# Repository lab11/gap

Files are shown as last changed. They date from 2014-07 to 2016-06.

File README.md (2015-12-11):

GAP: Generic Access Point
=========================
<div align="center">
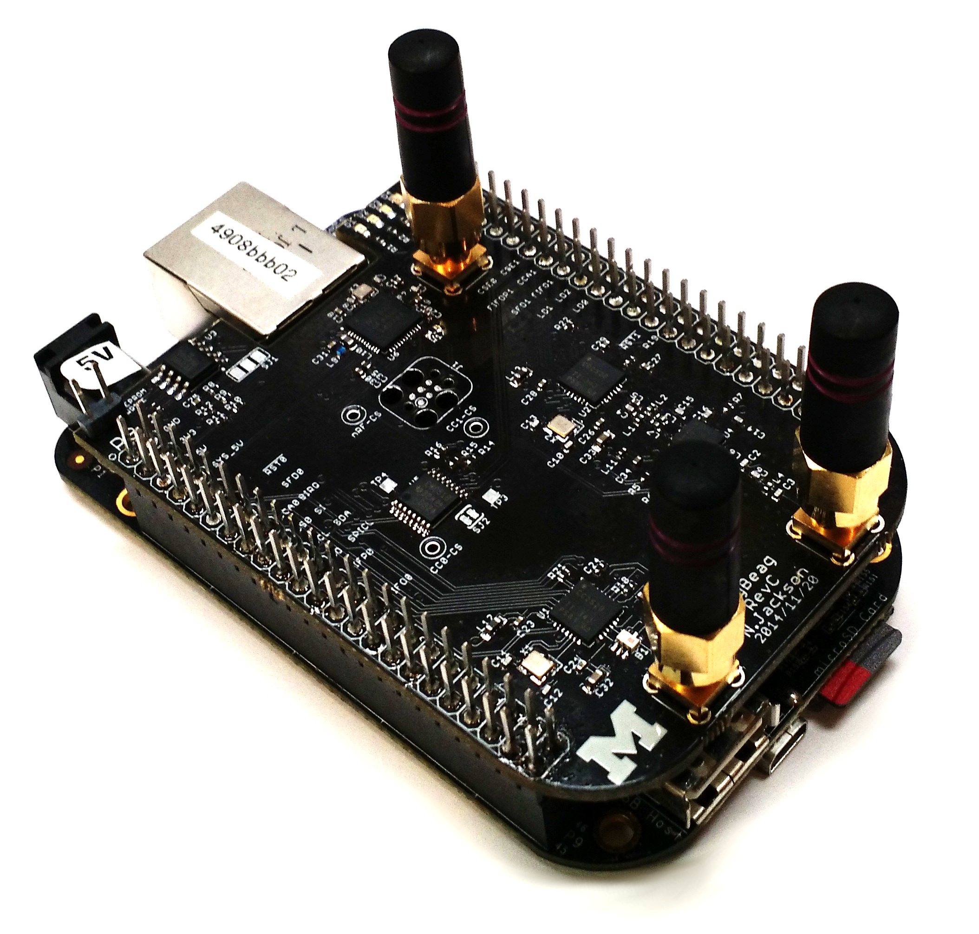
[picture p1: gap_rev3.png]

</div>

GAP is the WiFi router for low-power and embedded Internet of Things devices.
While WiFi routers provide ubiquitous Internet access for laptops and
smartphones, GAP provides Internet access for low-power sensors and wearable
devices. It supports both 802.15.4 and Bluetooth Low Energy.

GAP is implemented as a cape for the
[BeagleBone Black](http://beagleboard.org/black). It uses two TI CC2520 radios
and a Nordic nRF51822 radio to provide connectivity. Each radio has a linux
kernel module to allow userspace access to the radios.

Hardware
--------

The GAP cape features a SPI interface to two CC2520
radios, one of which is amplified with a CC2591, and one nRF51822 radio.
It also includes four LEDs.

Software
--------

The CC2520 radios are
[supported natively](https://github.com/torvalds/linux/blob/master/drivers/net/ieee802154/cc2520.c)
in newer versions of the Linux kernel (>=4.1).

The nRF51822 BLE radio is a work-in-progress. It can be used as a standalone
BLE radio (see [this repo](https://github.com/lab11/nrf5x-base) for a starting
point), but does not have great integration with the BBB at this point.

Setting Up GAP
--------------

To setup a BBB to work with GAP, follow these instructions:

1. Start with a recent build of Debian for the BBB. We suggest starting
with pretty new version of Debian, like that can be found
[here](http://elinux.org/Beagleboard:BeagleBoneBlack_Debian#Jessie_Snapshot_console).

2. Once that is setup, ssh to the BBB and update the kernel to the newest
version. This will not only make sure you're running the latest code,
but also ensure all of the kernel modules will be present.

        sudo apt-get update
        sudo apt-get install vim git lsb-release
        sudo /opt/scripts/tools/update_kernel.sh --beta --bone-channel

    Luckily [Robert C Nelson](https://github.com/RobertCNelson/)
    has made this really easy with a convenient script.

3. Now we have to setup the device tree overlay to let Linux know that
the the radios exist. The GAP overlay and others are setup in a repository also
maintained by RCN.

        git clone https://github.com/lab11/bb.org-overlays
        cd bb.org-overlays
        ./dtc-overlay.sh
        ./install.sh

    That puts the compiled overlay in the correct place, now we need to tell
    the BBB to use it at boot.

        vim /boot/uEnv.txt
        # Edit that line that looks like this to include the reference to GAP
        cape_enable=bone_capemgr.enable_partno=BB-GAP

4. Reboot to apply this.

        sudo reboot

Sniffing 15.4 Packets
---------------------

To make sure everything is working, it is pretty easy to get Linux to
print out the packets the radio is receiving.

1. Install the `wpan-tools` to configure all of the 15.4 devices.

        sudo apt-get install pkg-config libnl-3-dev libnl-genl-3-dev
        wget http://wpan.cakelab.org/releases/wpan-tools-0.5.tar.gz
        tar xf wpan-tools-0.5.tar.gz
        cd wpan-tools-0.5
        ./configure
        make
        sudo make install

1. Install `tcpdump` to view the packets.

        sudo apt-get install tcpdump

2. Configure the network devices. Be sure to set the channel and PANID
to match what is transmitting the 15.4 packets.

        iwpan phy phy0 set channel 0 11
        iwpan dev wpan0 del
        iwpan phy phy0 interface add wpan0 type node c0:98:e5:00:00:00:00:01
        iwpan dev wpan0 set pan_id 0x0022
        /sbin/ifconfig wpan0 up

3. Use `tcpdump` to view them.

        sudo tcpdump -i wpan0 -vvv
        
    OR, use a simple c program to read from the raw socket.
    
        cd linux
        gcc recv_raw_802154.c -o raw
        sudo ./raw
        
    OR, use a very similar python script:
    
        cd linux
        sudo python recv_raw_802154.py

RPL Border Router
----------------

GAP can be setup as a border router running a 6LoWPAN based mesh network
with RPL as a routing layer. It uses [unstrung](https://github.com/mcr/unstrung)
to provide the RPL implementation. The rest is supported by the Linux kernel.

To set this up:

1. Setup the radios and network interfaces:

        sudo iwpan phy phy1 set channel 0 23
        sleep 15
        sudo iwpan dev wpan1 del
        sleep 15
        sudo iwpan phy phy1 interface add wpan1 type node c0:98:e5:00:00:00:00:01
        sleep 15
        sudo iwpan dev wpan1 set pan_id 0x0022
        sleep 15
        sudo ip link add link wpan1 name lowpan1 type lowpan
        sleep 15
        sudo ifconfig lowpan1 up
        sleep 15
        sudo ifconfig wpan1 up

   Note: I've found that putting a sleep between those commands makes everything run smoothly.
   Calling them too quickly seems to break things (at least in the past, it's possible
   that newer commits have solved this issue).

2. Get unstrung.

        git clone https://github.com/mcr/unstrung.git
        cd unstrung
        make

    There may be commits that need to be applied to make this
    work. Look at unstrung pull requests to see if there are
    outstanding patches that are required.

3. Run unstrung.

        /home/debian/unstrung/programs/sunshine/sunshine --verbose --dagid 0x11112222333344445555666677778888 -i lowpan1 -W 10000 --stderr -R 1 --prefix 2607:f018:800:201:c298:e588:4400:1/64 -m

4. You should be able to ping a node:

        sudo ping6 2607:f018:800:201:c298:e522:2200:bb -s 16

<!--

### Setup EEPROM

Now we are getting close. We have told Linux about the kernel modules
and added the device tree overlay to a place where Linux can find it.
The last step is to get Linux to load the overlay which will then cause
it to load the kernel modules. This is where the EEPROM comes in.

When the BeagleBone Black boots it checks for EEPROMs present on any capes
and uses the configuration data in the EEPROM to load the correct device
tree overlay.

There exists a utility to create the hexdump (data.eeprom) to flash to the
EEPROM in `/software/utility`. After creating the hexdump, apply a jumper
to the write header near the EEPROM chip and use this command to flash the
EEPROM:

Choose 12 characters to serve as the serial number, in
the form `WWYY&&&&nnnn`. From the SRM:

    WW = 2 digit week of the year of production.
    YY = 2 digit year of production.
    &&&& = Assembly code, up to you to decide.
    nnnn = incrementing board number for week of production.

After creating `data.eeprom` with the eepromflasher utilty, write it to the
cape EEPROM as root.

    # On the BBB
    sudo su
    cat data.eeprom > /sys/bus/i2c/devices/1-0057/eeprom

Where `1-0057` is the default address for the GAP cape. This can be changed
by using the solder jumper pads near the EEPROM on the upper left corner of the
board.

Unfortunately, the BBB debian distribution fails to load custom firmware from
the EEPROM on boot, and requires an capemanager configuration file to be
edited.

    sudo vim /etc/default/capemgr

    # Add this line:
    CAPE=BB-BONE-GAP

CC2520 Border Router
--------------------

One way to use the CC2520s on GAP is with the TinyOS code in a related
repo: [RaspberryPi-CC2520](https://github.com/lab11/raspberrypi-cc2520).
The `BorderRouter` application can be compiled with `make gap`.
-->

<!--

### EEPROM

The capes feature EEPROM that will allow for the BeagleBone capemgr to auto load the driver
and configure pins on boot, in accordance with the Beaglebone Black SRM. There
exists a utility to create the hexdump (data.eeprom) to flash to the EEPROM in
beaglebone-cc2520/software/utility. After creating the hexdump, apply a jumper
to the write header and use this command to flash the EEPROM:

```bash
cat data.eeprom > /sys/bus/i2c/devices/1-0057/eeprom
```

Where 1-0057 is the default address for the Zigbeag cape. This can be changed by
using the solder jumper pads on the upper left corner of the board.

Software
--------

### Install

This guide assumes the default Angstrom distro running under root.<br/>
Clone the repo to wherever you feel fit:

```bash
git clone https://github.com/lab11/beaglebone-cc2520.git
```

Note: you may have to follow the directions [here](http://derekmolloy.ie/fixing-git-and-curl-certificates-problem-on-beaglebone-blac/) to get git working correctly.

An install script is located in /software. <br/>
The script will copy the Device Tree Overlay (DTO) to /lib/firmware, and the driver to /lib/modules/KERNEL_VERSION, where KERNEL_VERSION is your current running kernel version number. <br/>
Navigate to software/ and run the install script:

```bash
cd beaglebone-cc2520/software/
./install
```

If using the Zigbeag cape with configured EEPROM, just plug it in and reboot the beaglebone and your board will be fully functional.

If EEPROM is not configured, to load the Device Tree Overlay manually:

```bash
echo BB-BONE-CC2520 > /sys/devices/bone_capemgr.9/slots
```
This command should complete with no output.
To check that the DTO has loaded, run:

```bash
cat /sys/devices/bone_capemgr.9/slots
```
Note: bone_capemgr.9 may actually be bone_capemgr.8 for different beaglebones. <br/>
You should check to see that there is now an override board in a slot after the virtual HDMI cape. <br/>
Here is my output:

```
 0: 54:PF---
 1: 55:PF---
 2: 56:PF---
 3: 57:PF---
 4: ff:P-O-L Bone-LT-eMMC-2G,00A0,Texas Instrument,BB-BONE-EMMC-2G
 5: ff:P-O-L Bone-Black-HDMI,00A0,Texas Instrument,BB-BONELT-HDMI
 7: ff:P-O-L Override Board Name,00A0,Override Manuf,BB-BONE-CC2520
```

Now that the DTO is loaded, the pins are now muxed correctly for the cc2520 board. We can now load the driver with:

```bash
modprobe cc2520
```

This command should complete with no output. <br/>
You can check that the driver loaded successfully with:

```bash
lsmod
```

#### Testing
You should now have a functioning Zigbeag cape. There are test programs located in software/driver/tests. Try running the write and read program on two beaglebones, and you should be able to see them talking to each other.

#### Install Issues
If you run into issues with any of the above commands, check dmesg for any output from the kernel. <br/>
Run this to check for issues with loading the DTO:

```bash
dmesg | grep bone_capemgr
```

Run this to check for issues with loading the driver:

```bash
dmesg | grep cc2520
```

### Kernel Module

In order to support the CC2520, you need the kernel module located in software/driver. The install script will automatically copy this into /lib/modules/KERNEL_VERSION. <br/>
This driver has been adapted from the [Linux CC2520 Driver](https:/github.com/ab500/linux-cc2520-driver). <br/>
If you would like to compile the driver from source, there is some setup involved.
I've found it easiest to use a symlink and compile from the current kernel on the Beaglebone.

```bash
opkg update
opkg upgrade
```
It would be a good idea to reboot at this point

```bash
opkg install kernel-headers
opkg install kernel-dev
cd /usr/src/kernel
make scripts
ln -s /usr/src/kernel /lib/modules/$(uname -r)/build
```

You can then navigate to beaglebone-cc2520/software/driver and run make to compile the driver. Make sure you re-run the install script, which will copy cc2520.ko to /lib/modules/KERNEL_VERSION and run depmod -a to register the driver with your system. -->

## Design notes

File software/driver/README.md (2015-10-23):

Custom Kernel Modules for GAP
=============================

These modules are a little out of date, but at one time supported the
radios on GAP.

gapspi.ko
---------

This module uses SPI0 and the onboard demux to switch the SPI bus and 
single chip select to multiple peripherals.

nrf51822.ko
-----------

This provides a SPI connection to the nRF51822.

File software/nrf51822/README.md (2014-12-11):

Setting Up The nRF51822
=======================

This guide explains how to get going with running code on nRF51822 based
platforms.

Setup
=====

1. Get the makefiles. This is an external set of makefiles for the nRF51822.
Apparently they are better than the ones that ship with Nordic's SDK. They
are also on github and can be modified as needed.

        git clone https://github.com/hlnd/nrf51-pure-gcc-setup.git

1. Make sure you have the [arm-none-eabi-gcc](https://launchpad.net/gcc-arm-embedded)
toolchain. You just need the binaries for your platform.

1. Get the nRF51822 SDK and S120 soft device from the
[downloads page](https://www.nordicsemi.com/eng/Products/Bluetooth-Smart-Bluetooth-low-energy/nRF51822?resource=20339).
You want the "nRF51 SDK Zip File" and the "S120 nRF51822 SoftDevice (Production ready)".
You do need to buy a nRF51822 evm kit to get access to these, because companies
are the worst.

1. Get the [Segger flashing tools](http://www.segger.com/jlink-software.html)
for your platform.

Install an Application
======================

1. Make sure the path to the SDK is set correctly in the application
makefile (or override it in your environment).

1. Make sure the path to the gcc Makefiles is set correctly in the application
makefile (or override it in your environment).

1. Just once you need to load the soft device onto the nRF51822. In the application
directory:

        sudo make flash-softdevice SOFTDEVICE=/path/to/softdevice/s120_nrf51822_X.X.X_softdevice.hex

1. Now compile and load the application code.

        sudo make flash

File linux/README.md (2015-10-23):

BBB + GAP + Linux
======================

This provides some instructions for using GAP with Linux.

Setup from new BBB Install
--------------------------

After flashing the BBB, ssh to it and:
```
# lockout root
edit /etc/ssh/sshd_config

# change password
passwd

# packages
sudo apt-get update
sudo apt-get install vim git lsb-release

# update kernel
sudo /opt/scripts/tools/update_kernel.sh --beta --bone-channel

# Add overlays
git clone https://github.com/lab11/bb.org-overlays
cd bb.org-overlays
./dtc-overlay.sh
./install.sh

# Make GAP load on boot
edit /boot/uEnv.txt
  cape_enable=bone_capemgr.enable_partno=BB-GAP

# Reboot
sudo reboot

# Verify
/sbin/ifconfig -a

# Get WPAN tools
sudo apt-get install pkg-config libnl-3-dev libnl-genl-3-dev
wget http://wpan.cakelab.org/releases/wpan-tools-0.5.tar.gz
tar xf wpan-tools-0.5.tar.gz
cd wpan-tools-0.5
./configure
make
sudo make install

```

Sniff broadcast packets
-----------------------

```
sudo apt-get install tcpdump

iwpan phy phy0 set channel 0 11
iwpan dev wpan0 del
iwpan phy phy0 interface add wpan0 type node c0:98:e5:00:00:00:00:01
iwpan dev wpan0 set pan_id 0x0022
/sbin/ifconfig wpan0 up

sudo tcpdump -i wpan0 -vvv
```

Configuring CC2520 with 6LoWPAN
------------------

Once the hardware and software packages are setup, the next step is the art
of using the in-flux tools to get things configured.

1. Set the channel on the physical device.

        iwpan phy phy0 set channel 0 11

1. Create the wpan device. If it exists, delete it first. We need to set the
address.

        iwpan dev wpan0 del
        iwpan phy phy0 interface add wpan0 type node c0:98:e5:00:00:00:00:01

2. Configure the wpan device with a PAN id.

        iwpan dev wpan0 set pan_id 0x0022

3. Add a lowpan device.

        ip link add link wpan0 name lowpan0 type lowpan

4. Bring things up.

        ifconfig lowpan0 up
        ifconfig wpan0 up

5. Ping!

        ping6 fe80::<something>%lowpan0

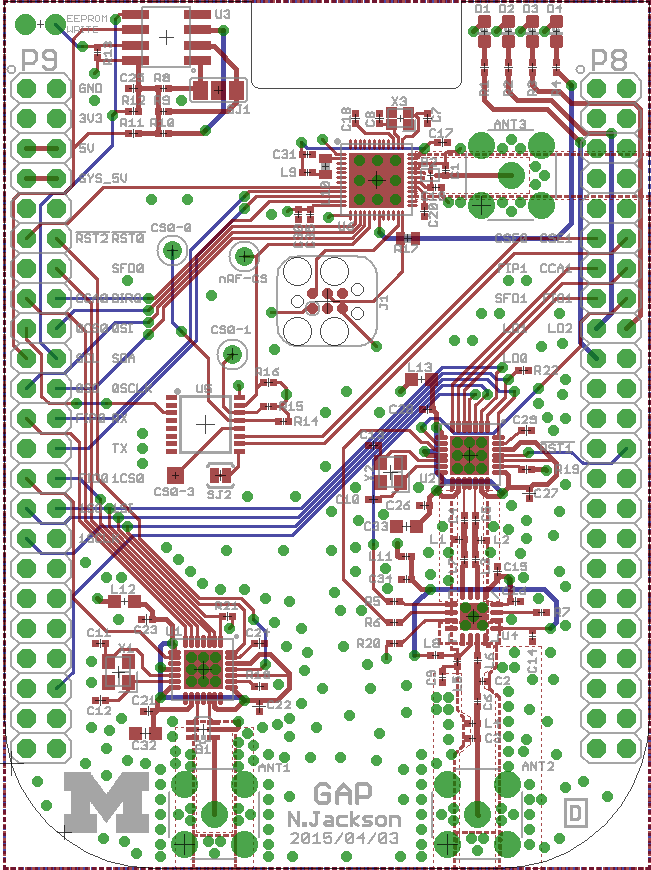
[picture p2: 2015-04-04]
hardware/eagle/bbb-cc2520/rev_d/bbb-cc2520_pcb.png

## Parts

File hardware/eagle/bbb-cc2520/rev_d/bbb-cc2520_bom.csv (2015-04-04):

Qty | Value | Device | Package | Parts | Description | DIGIKEY | SAMTEC | MAJOR LEAGUE
3 | MOLEX_WM5544-ND | MOLEX_WM5544-ND | MOLEX_WM5544-ND | ANT1, ANT2, ANT3 | Through-hole SMA Antenna | WM5544-ND
1 | 2450BM15A0002 | 2450BM15A0002 | 2450BM | B1 | BALUN JTI MATCHED ZIGBEE | 712-1536-1-ND
1 | BAL-NRF01D3 | BAL-NRF01D3 | BAL-NRF01D3 | B2 | 50 ohm nominal input / conjugate match balun to nRF51422-QFAA, | 497-13637-1-ND
1 | 0.8pF | CAPACITOR | 0402_CAP | C1 | 0402 Capacitor | 490-6269-1-ND
1 | 1pF | C-EUC0402 | C0402 | C2 | Capacitor, 1p, 0402, NP0, +/-0.1pF 50V | 490-6206-1-ND
1 | 2.7pF | C-EUC0402 | C0402 | C3 | Capacitor, 2p7, 0402, NP0, +-0.25pF, 50V | 490-5934-1-ND
1 | 3pF | C-EUC0402 | C0402 | C4 | Capacitor, 3p, 0402, NP0, +-0.25pF, 50V | 490-5872-1-ND
1 | 3.9pF | C-EUC0402 | C0402 | C5 | Capacitor, 3p9, 0402, NP0, +-0.25pF, 50V | 490-1272-1-ND
1 | 6.8pF | C-EUC0402 | C0402 | C6 | Capacitor, 6p8, 0402, NP0, +-0.25pF 50V | 490-5949-1-ND
2 | 12pF | CAPACITOR | 0402_CAP | C7, C8 | 0402 Capacitor | 490-6197-1-ND
1 | 15pF | C-EUC0402 | C0402 | C9 | Capacitor, 15p, 0402, NP0, 5%, 50V | 490-5888-1-ND
4 | 27pF | C-EUC0402 | C0402 | C10, C11, C12, C13 | Capacitor, 27p, 0402, NP0, 5%, 50V | 490-5869-1-ND
3 | 1nF | C-EUC0402 | C0402 | C14, C15, C16 | Capacitor, 1n, 0402, NP0, 5%, 50V | 490-3244-1-ND
2 | 1nF | CAPACITOR | 0402_CAP | C17, C18 | 0402 Capacitor | 490-1303-1-ND
1 | 2.2nF | CAPACITOR | 0402_CAP | C19 | 0402 Capacitor | 490-5419-1-ND
1 | 47nF | CAPACITOR | 0402_CAP | C20 | 0402 Capacitor | 445-1264-1-ND
9 | 100nF | C-EUC0402 | C0402 | C21, C22, C23, C24, C25, C26, C27, C28, C29 | Capacitor, 100n, 0402, X5R, 10%, 10V | 490-1318-1-ND
1 | 0.1uF | CAPACITOR | 0402_CAP | C30 | 0402 Capacitor | 445-4952-1-ND
1 | 1uF | CAPACITOR | 0402_CAP | C31 | 0402 Capacitor | 1276-1513-1-ND
2 | 1uF | C-EUC0603 | C0603 | C32, C33 | Capacitor, 1u0, 0603, X5R, 10%, 6.3V | 490-1550-1-ND
1 | 2.2uF | C-EUC0402 | C0402 | C34 | Capacitor, 2u2, 0402, X5R, 20%, 4V | 490-4518-1-ND
1 | 4.7uF | CAPACITOR | 0402_CAP | C35 | 0402 Capacitor | 445-5947-1-ND
1 | GREEN | LED0603 | LED-0603 | D1 | LEDs | 160-1834-1-ND
1 | RED | LED0603 | LED-0603 | D2 | LEDs | 160-1835-1-ND
1 | BLUE | LED0603 | LED-0603 | D3 | LEDs | 160-1837-1-ND
1 | YELLOW | LED0603 | LED-0603 | D4 | LEDs | 160-1831-1-ND
1 | JUMPER-PTH-2-NO | JUMPER-PTH-2-NO | PTH-JUMPER-2-NO_NO_SILK | J2 |  | 3M9447-ND
4 | 1nH | INDUCTOR0402 | C0402 | L1, L2, L3, L4 | Inductor, 1n0, 0402, Monolithic type, +/-0.3 nH | 490-2610-1-ND
1 | 1.1nH | INDUCTOR0402 | C0402 | L5 | Inductor, 1n1, 0402, Monolithic type, +/-0.3 nH | 490-6567-1-ND
1 | 1.5nH | INDUCTOR0402 | C0402 | L6 | Inductor, 1n5, 0402, wire-wound type, +/-0.1 nH | 490-6782-1-ND
1 | 2nH | INDUCTOR0402 | C0402 | L7 | Inductor, 2n0, 0402, +/-0.3 nH | 490-6569-1-ND
1 | 5.1nH | INDUCTOR0402 | C0402 | L8 | Inductor, 5n1, 0402, +/-0.3 nH | 490-6573-1-ND
1 | 15nH | INDUCTOR0402 | 0402_CAP | L9 |  | 587-1521-1-ND
1 | 10uH | INDUCTOR0603 | 0603_CAP | L10 |  | 490-4025-1-ND
1 | 1k Ohm | INDUCTOR0402 | C0402 | L11 | EMI filter bead, 0402 1Kohms GHz Band Gen Use | 490-3999-1-ND
2 | 1k Ohm | INDUCTOR0603 | L0603 | L12, L13 | EMI filter bead, 0603 1Kohms GHz Band Gen Use | 490-1015-1-ND
2 | BBB_HEADERS | BBB_HEADERS | BBB_HEADERS | P8, P9 | 2x23 Pin Header |  | SSQ-123-03-T-D | SSHQ-123-D-08-G-LF
4 | 470 ohm | R-US_R0402 | R0402 | R1, R2, R3, R4 | RESISTOR, American symbol | RHM470CDCT-ND
2 | 1k 1% | R-US_R0402 | R0402 | R5, R6 | RESISTOR, American symbol | RHM1.00KCDCT-ND
1 | 4.3k | R-US_R0402 | R0402 | R7 | RESISTOR, American symbol | 1276-4078-1-ND
3 | 4.75k | R-US_R0402 | R0402 | R8, R9, R10 | RESISTOR, American symbol | 1276-4083-1-ND
2 | 5.6k 5% | R-US_R0402 | R0402 | R11, R12 | RESISTOR, American symbol | RHM5.6KCECT-ND
4 | 10k 1% | R-US_R0402 | R0402 | R13, R14, R15, R16 | RESISTOR, American symbol | RHM10.0KCDCT-ND
1 | 12k | RESISTOR | 0603-RES | R17 | Resistor | RHM12.0KCDCT-ND
2 | 56k 1% | R-US_R0402 | R0402 | R18, R19 | RESISTOR, American symbol | P56.0KLCT-ND
1 | 330k 1% | R-US_R0402 | R0402 | R20 | RESISTOR, American symbol | RHM330KCFCT-ND
2 | 1M 1% | R-US_R0402 | R0402 | R21, R22 | RESISTOR, American symbol | RHM1.00MCDCT-ND
3 | TEST_POINT_0.040IN | TEST_POINT_0.040IN | TESTPOINT_0.040IN | TP0, TP1, TP2 | 0.040in Test Point | 5001K-ND
2 | CC2520 | CC2520 | S-PVQFN-N28 | U1, U2 | 2.4 GHZ IEEE 802.15.4/ZIGBEE® RF TRANSCEIVER | 296-22996-1-ND
1 | CAT24C256WI-GT3 | CAT24C256WI-GT3 | SOIC-8 | U3 | 256kb Serial CMOS EEPROM | CAT24C256WI-GT3OSCT-ND
1 | CC2591 | CC2591 | PVQFN-16 | U4 | 2.4GHz Range Extender | 296-23603-1-ND
1 | CD4051B-53B | CD4051B-53B | TSSOP16 | U5 | IC MUX/DEMUX 8x1 16TSSOP | 296-11993-1-ND
1 | NRF51822QF | NRF51822QF | QFN-48-6MM | U6 | Multiprotocol Bluetooth® 4.0 low energy/2.4 GHz RF SoC 32kB/256kB | 1490-1042-1-ND
2 | NX2520SA | NX2520SA | NX2520SA | X1, X2 | CRYSTAL 32MHZ 10PF SMD | 644-1065-1-ND
1 | 16MHz | TXC-8Y | TXC-8Y | X3 | 2mmx1.6mm SMD Crystal | 887-2003-1-ND

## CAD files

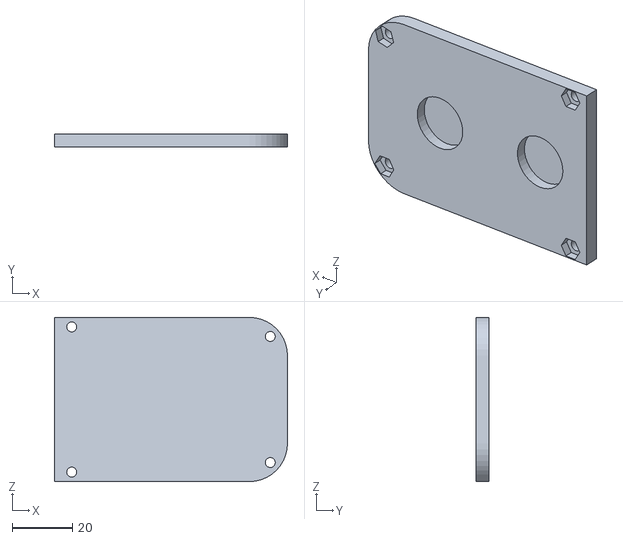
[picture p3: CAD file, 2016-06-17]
3d/beagle_bone_gateway_magnet_plate_v3.STL
77.5 x 4.48 x 54.6

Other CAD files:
3d/beagle_bone_gateway_magnet_plate.SLDPRT
3d/beagle_bone_gateway_magnet_plate_v2.STL
3d/beagle_bone_gateway_magnet_plate.STL

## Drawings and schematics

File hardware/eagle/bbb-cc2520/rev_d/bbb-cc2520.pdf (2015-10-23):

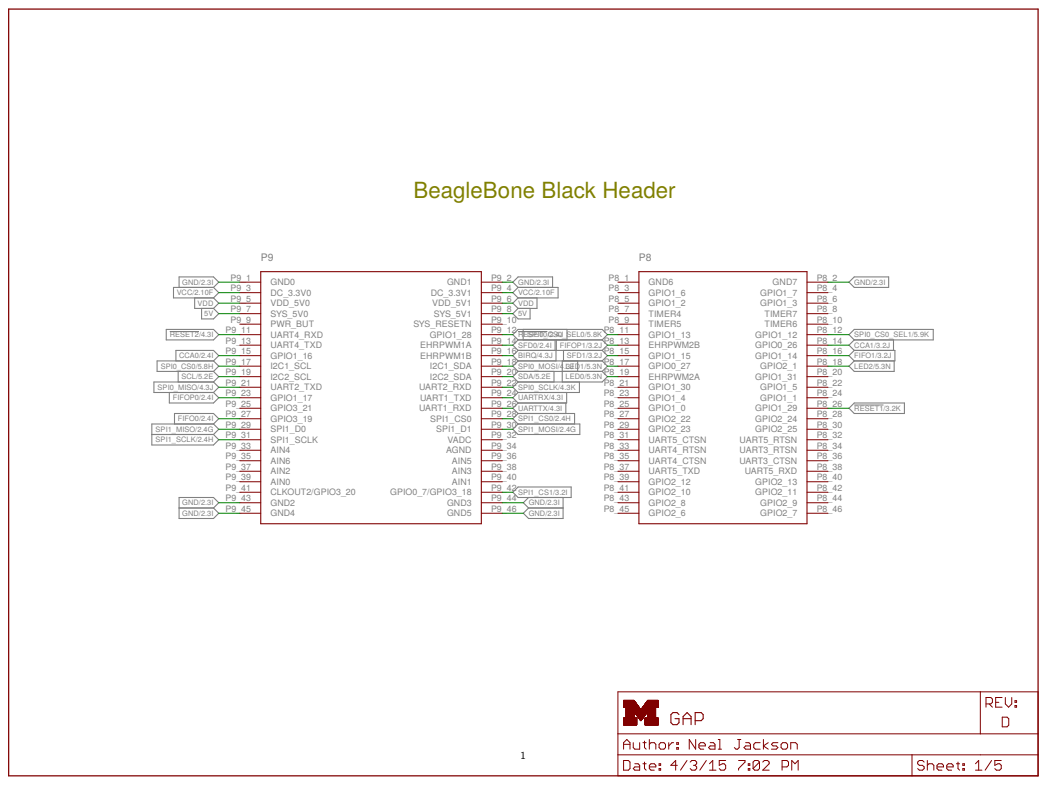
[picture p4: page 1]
1 BeagleBone Black Header GND0 P9_1; GND1; P9_4 VDD_5V0 P9_5; VDD_5V1; P9_6 SYS_5V0 P9_7; SYS_5V1; P9_8 PWR_BUT P9_9; SYS_RESETN; P9_10 UART4_RXD P9_11; GPIO1_28; P9_12 UART4_TXD P9_13; EHRPWM1A; P9_14 GPIO1_16 P9_15; EHRPWM1B; P9_16 I2C1_SCL P9_17; I2C1_SDA; P9_18 I2C2_SCL P9_19; I2C2_SDA; P9_20 UART2_TXD P9_21; UART2_RXD; P9_22 GPIO1_17 P9_23; UART1_TXD; P9_24 GPIO3_21 P9_25; UART1_RXD; P9_26 GPIO3_19 P9_27; SPI1_CS0; P9_28 SPI1_D0 P9_29; SPI1_D1; P9_30 SPI1_SCLK P9_31; VADC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

# CC2520. Index: 0, no amplifier

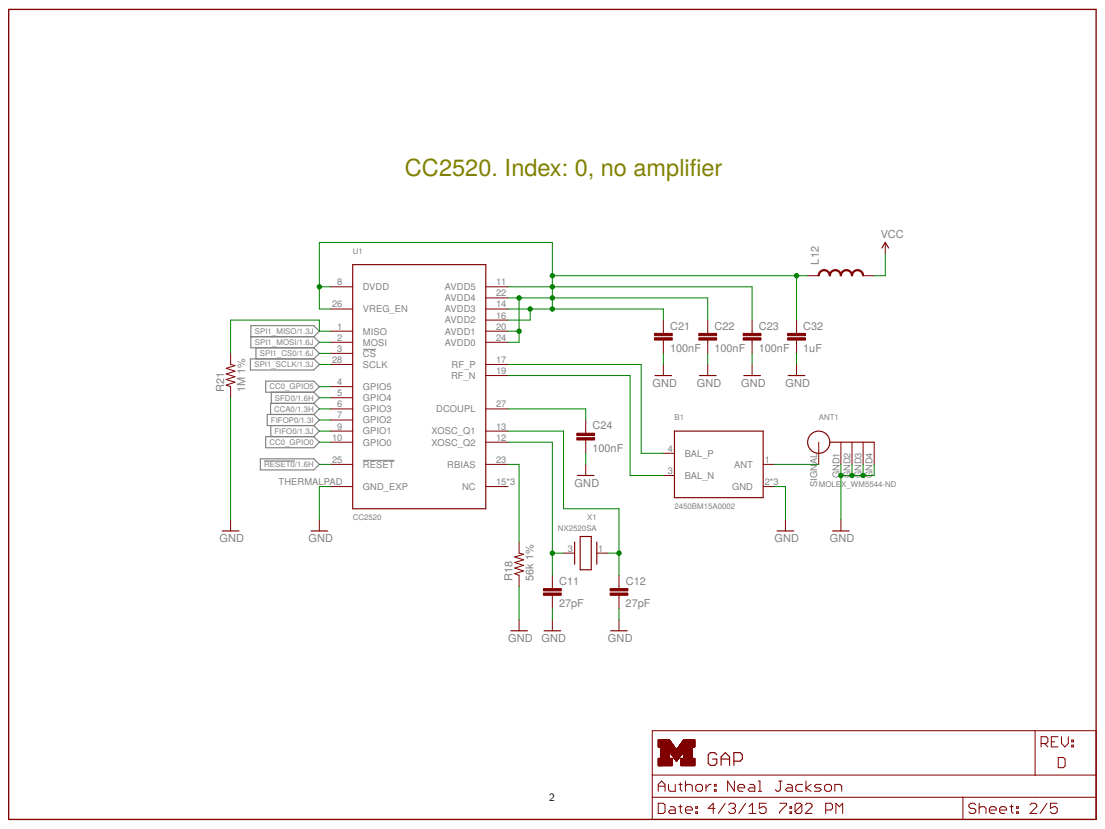
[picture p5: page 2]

14
16

# CC2520. Index: 1, with amplifier

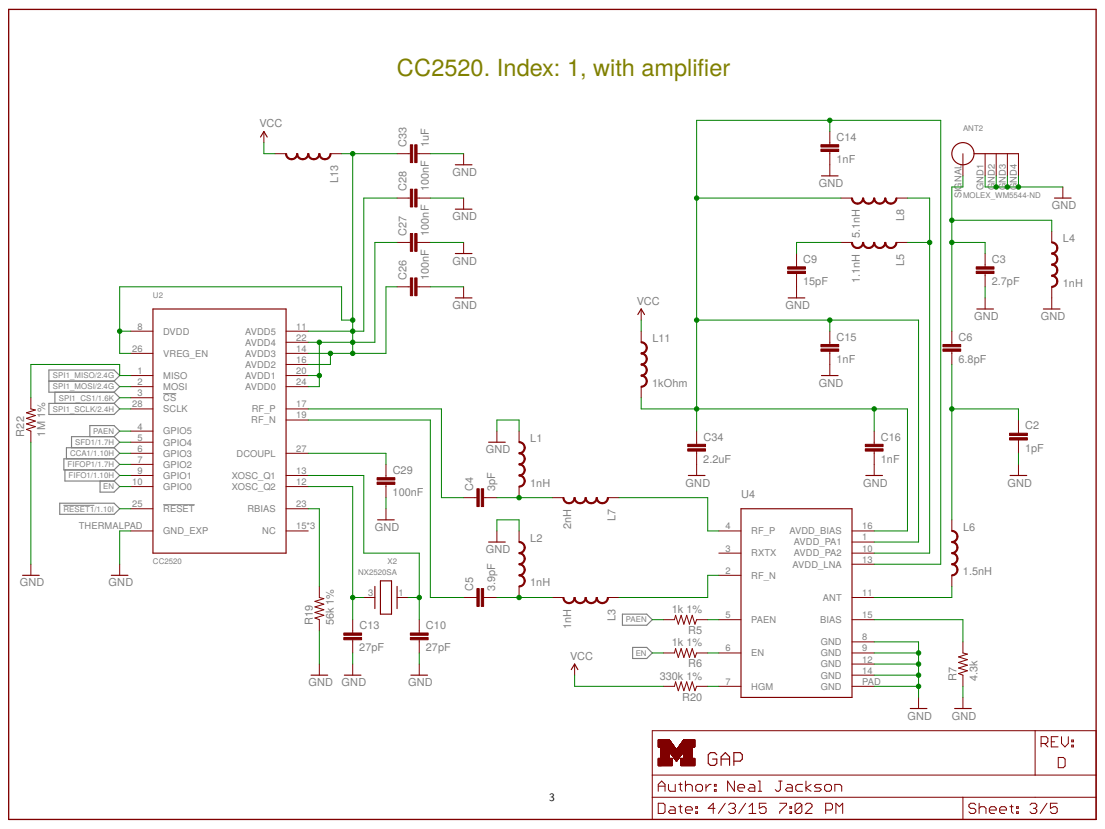
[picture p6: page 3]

14
16

# nRF51822

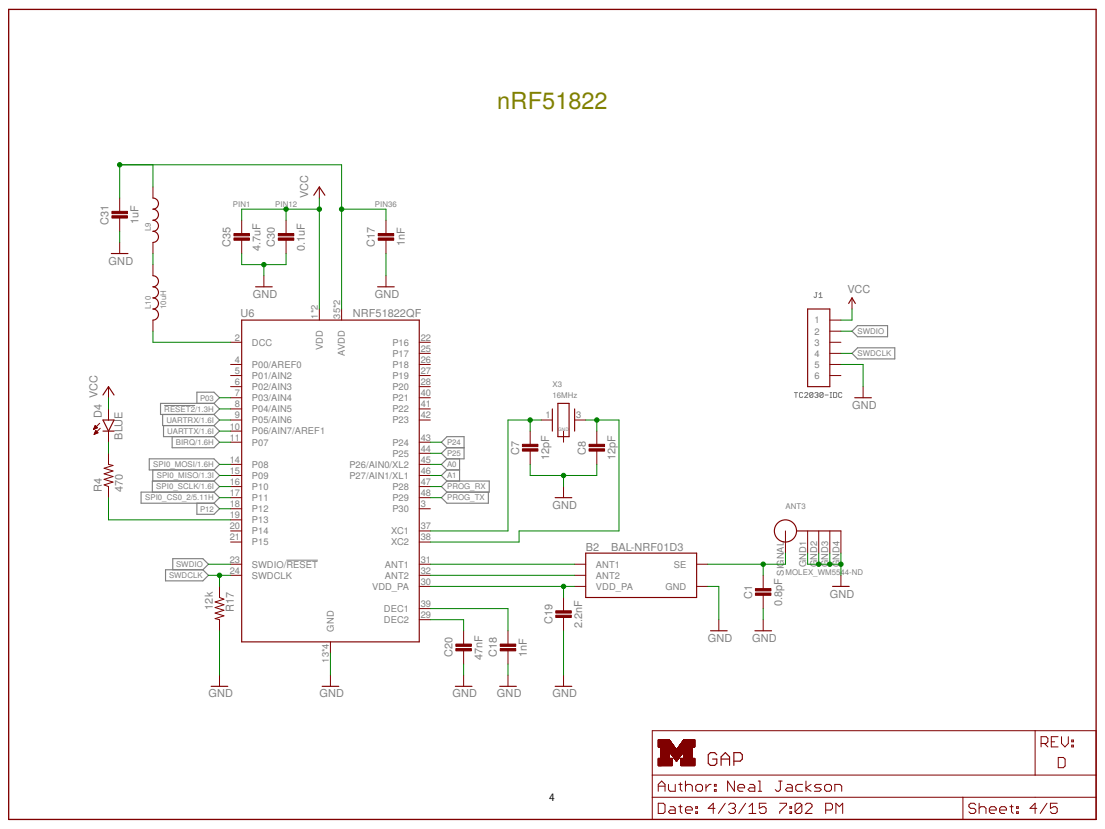
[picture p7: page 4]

# Chip Select DeMux

# EEPROM

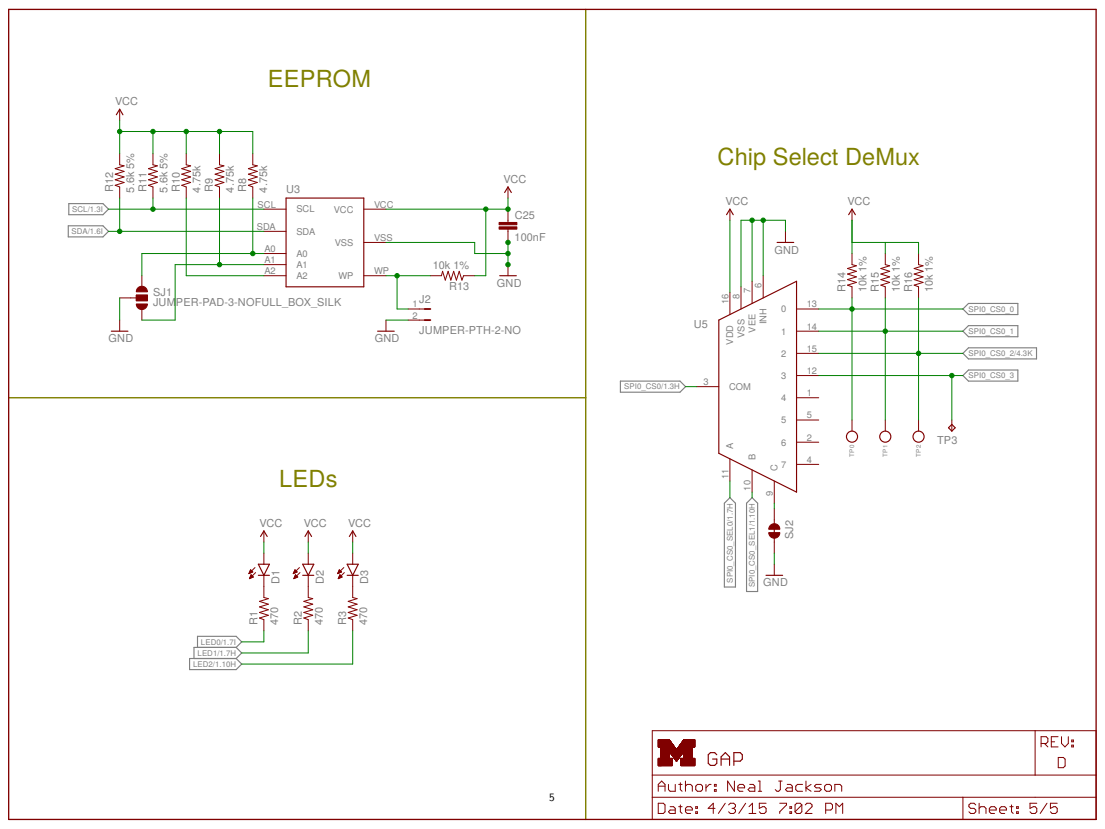
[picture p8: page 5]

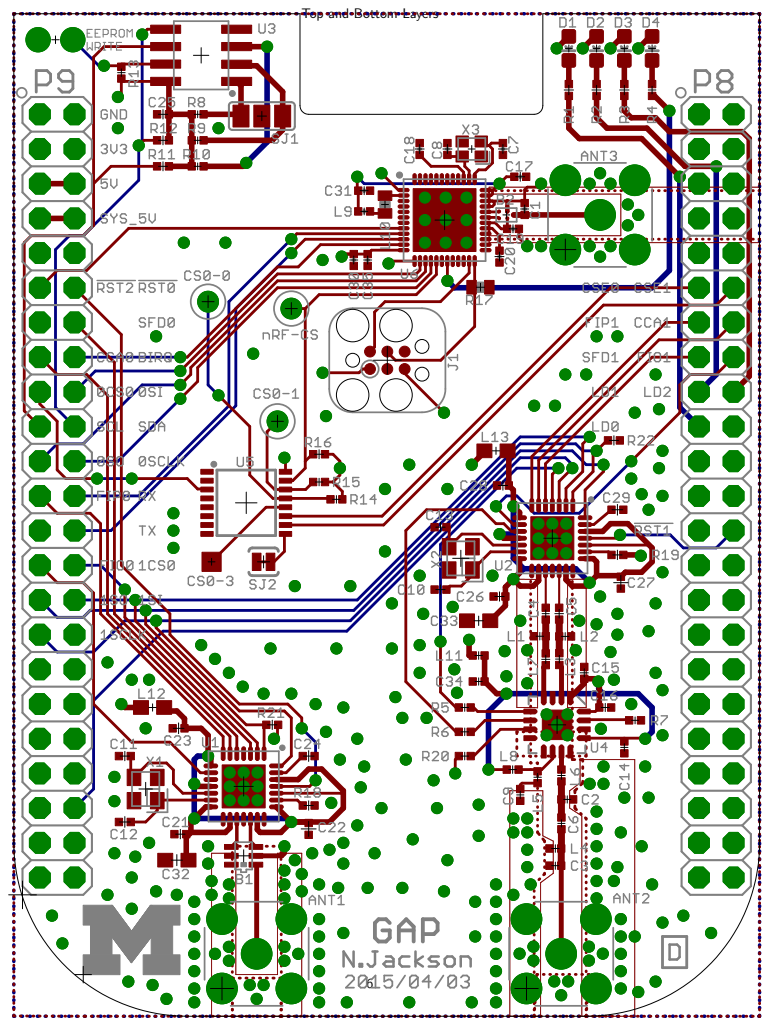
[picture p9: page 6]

Top and Bottom Layers

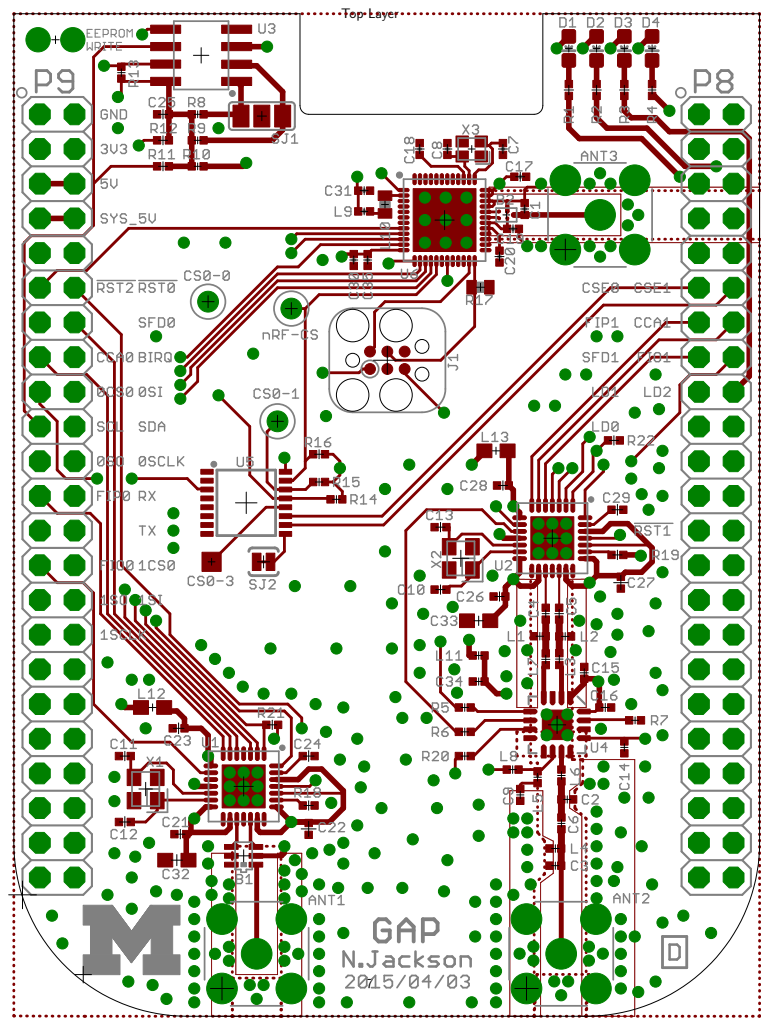
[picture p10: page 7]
Top Layer

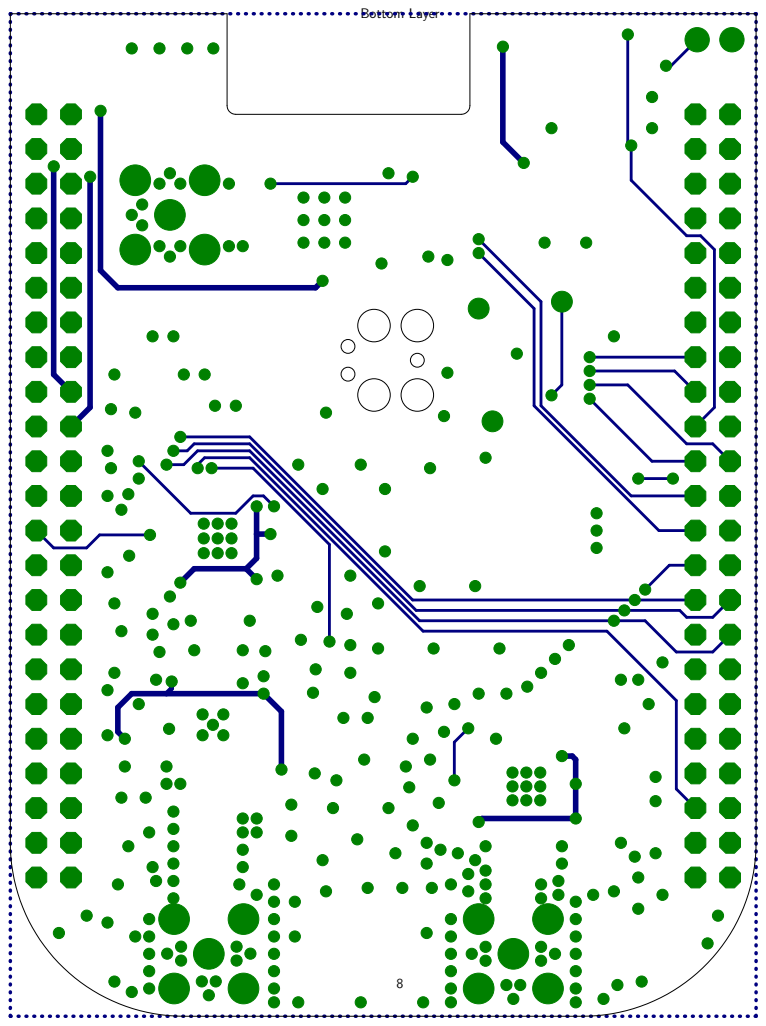
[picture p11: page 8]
Bottom Layer

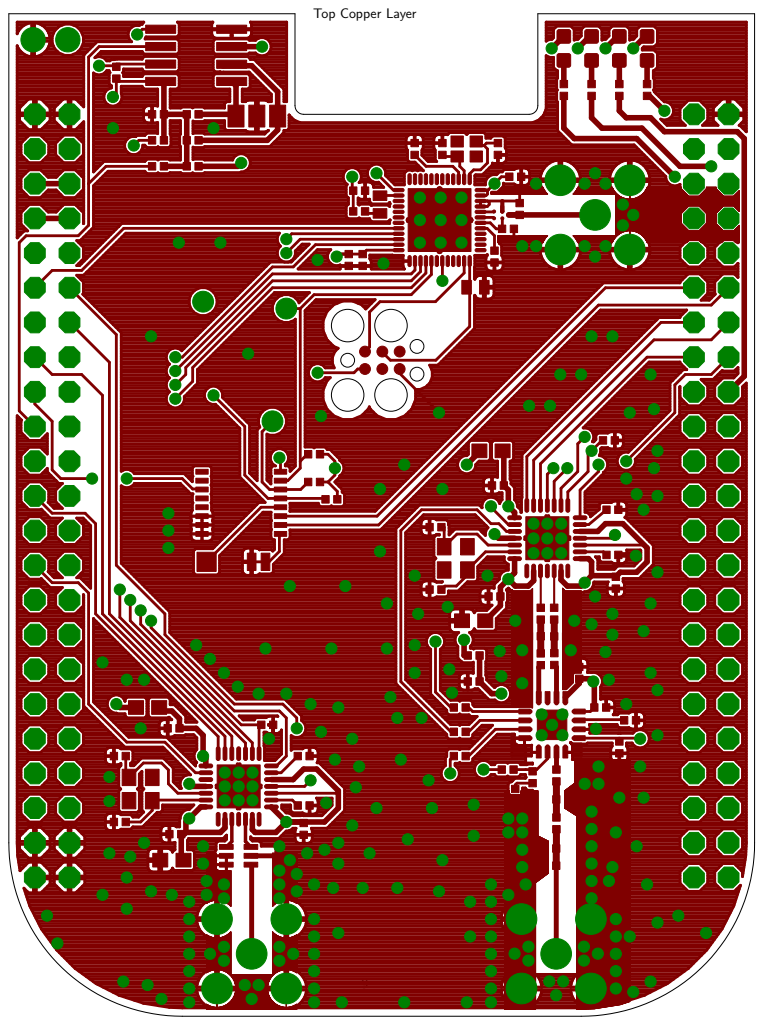
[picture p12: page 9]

Top Copper Layer

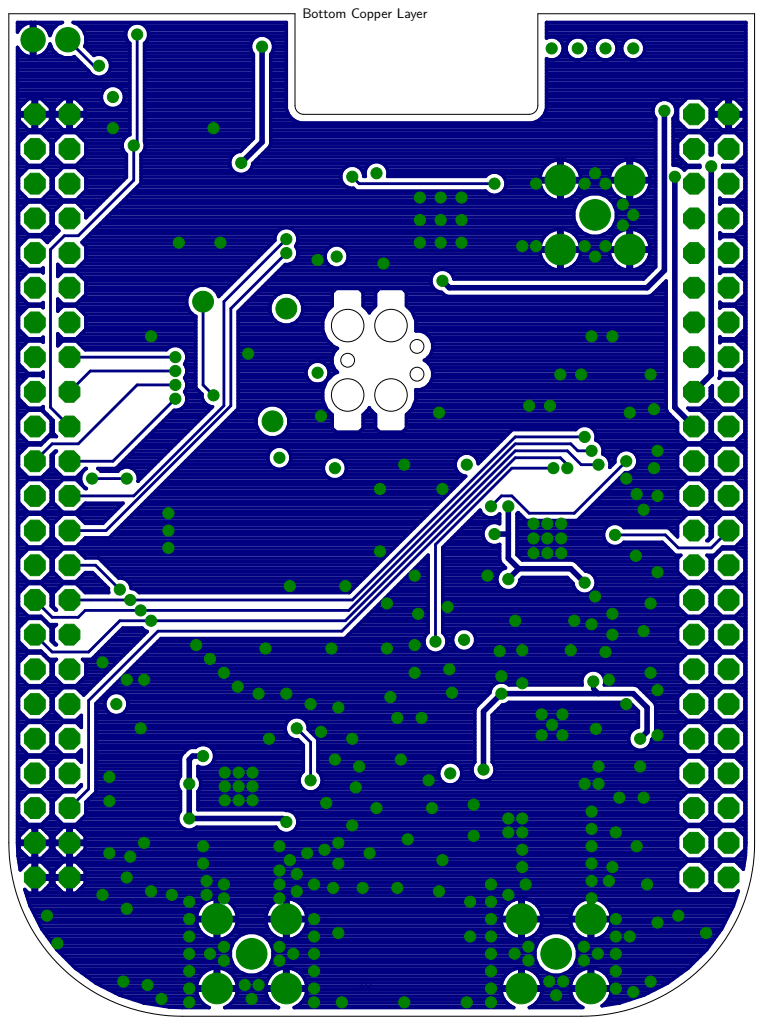
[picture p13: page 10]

Bottom Copper Layer

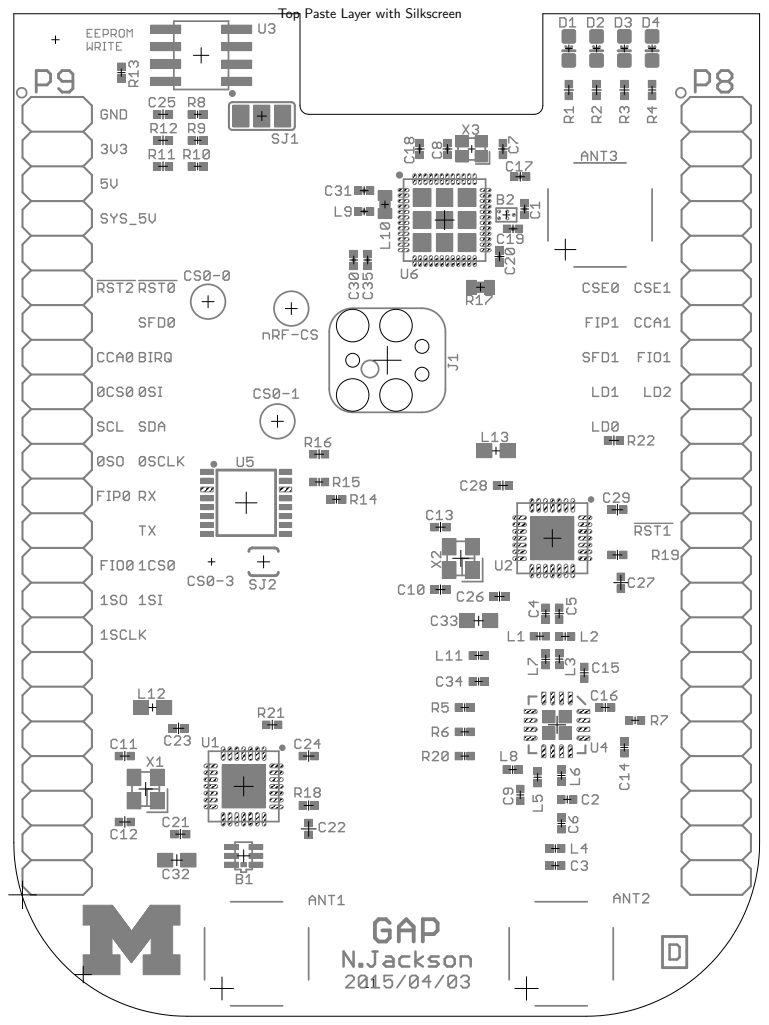
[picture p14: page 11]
Top; Paste Layer with Silkscreen

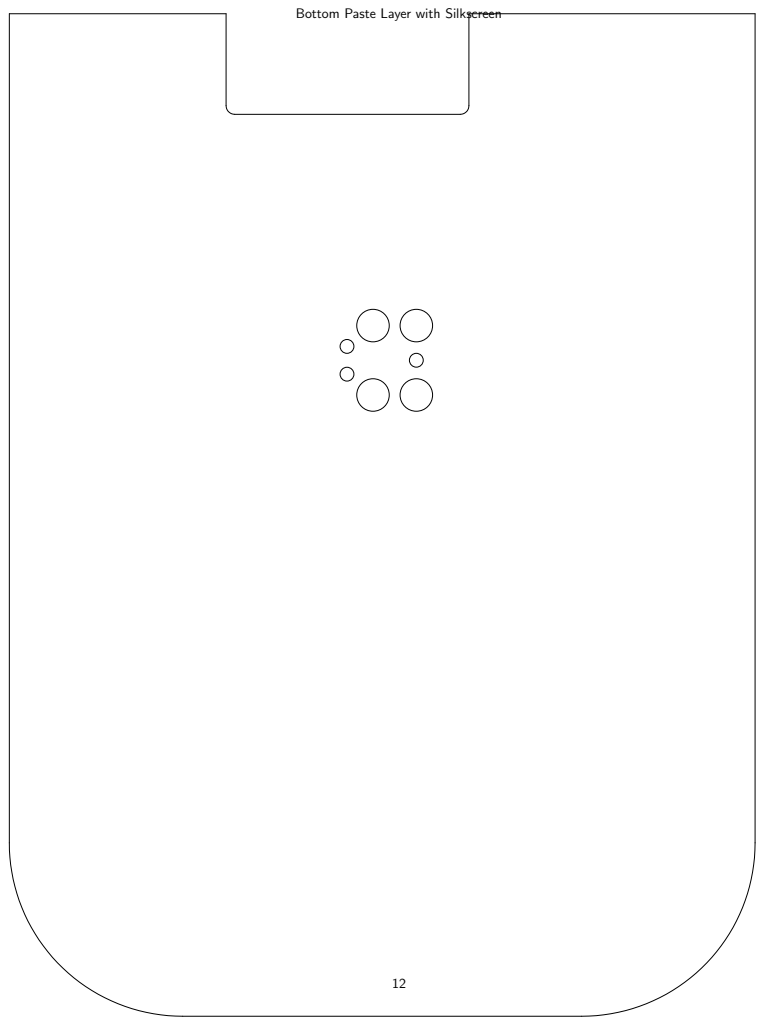
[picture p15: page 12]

Bottom Paste Layer with Silkscreen


Top and Bottom Layers 1:1 Scale


Top Layer 1:1 Scale


Bottom Copper Layer 1:1 Scale

Qty | Value | Device
| 3 MOLEX_WM5544-ND | MOLEX_WM5544-ND
| 12450BM15A0002 | 2450BM15A0002
| 1 BAL-NRF01D3 | BAL-NRF01D3
| 10.8pF | CAPACITOR
| 11pF | C-EUC0402
| 12.7pF | C-EUC0402
| 13pF | C-EUC0402
| 13.9pF | C-EUC0402
| 16.8pF | C-EUC0402
| 212pF | CAPACITOR
| 115pF | C-EUC0402
| 427pF | C-EUC0402
| 31nF | C-EUC0402
| 21nF | CAPACITOR
| 12.2nF | CAPACITOR
| 147nF | CAPACITOR
| 9100nF | C-EUC0402
| 10.1uF | CAPACITOR
| 11uF | CAPACITOR
| 21uF | C-EUC0603
| 12.2uF | C-EUC0402
| 14.7uF | CAPACITOR
| 1 GREEN | LED0603
| 1 RED | LED0603
| 1 BLUE | LED0603
| 1 YELLOW | LED0603
| 1JUMPER-PTH-2-NO | JUMPER-PTH-2-NO
| 41nH | INDUCTOR0402
| 11.1nH | INDUCTOR0402
| 11.5nH | INDUCTOR0402
| 12nH | INDUCTOR0402
| 15.1nH | INDUCTOR0402
| 115nH | INDUCTOR0402
| 110uH | INDUCTOR0603
| 11k Ohm | INDUCTOR0402
| 21k Ohm | INDUCTOR0603
| 2 BBB_HEADERS | BBB_HEADERS
| 4470 ohm | R-US_R0402
| 21k 1% | R-US_R0402
| 14.3k | R-US_R0402
| 34.75k | R-US_R0402
| 25.6k 5% | R-US_R0402
| 410k 1% | R-US_R0402
| 112k | RESISTOR
| 256k 1% | R-US_R0402
| 1330k 1% | R-US_R0402
| 21M 1% | R-US_R0402
| 3 TEST_POINT_0.040IN | TEST_POINT_0.040IN
| 2 CC2520 | CC2520
| 1 CAT24C256WI-GT3 | CAT24C256WI-GT3
| 1 CC2591 | CC2591
| 1 CD4051B-53B | CD4051B-53B

1 NRF51822QF | NRF51822QF 2 NX2520SA | NX2520SA 116MHz | TXC-8Y

Parts
ANT1, ANT2, ANT3
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
C7, C8
C9
C10, C11, C12, C13
C14, C15, C16
C17, C18
C19
C20
C21, C22, C23, C24, C25, C26, C27, C28, C29 C30
C31
C32, C33
C34
C35
D1
D2
D3
D4
J2
L1, L2, L3, L4
L5
L6
L7
L8
L9
L10
L11
L12, L13
P8, P9
R1, R2, R3, R4
R5, R6
R7
R8, R9, R10
R11, R12
R13, R14, R15, R16
R17
R18, R19
R20
R21, R22
TP0, TP1, TP2
U1, U2
U3
U4
U5

U6
X1, X2
X3

Description
Through-hole SMA Antenna
BALUN JTI MATCHED ZIGBEE
50 ohm nominal input / conjugate match balun to nRF51422-QFAA, 0402 Capacitor
Capacitor, 1p, 0402, NP0, +/-0.1pF 50V
Capacitor, 2p7, 0402, NP0, +-0.25pF, 50V
Capacitor, 3p, 0402, NP0, +-0.25pF, 50V Capacitor, 3p9, 0402, NP0, +-0.25pF, 50V Capacitor, 6p8, 0402, NP0, +-0.25pF 50V 0402 Capacitor
Capacitor, 15p, 0402, NP0, 5%, 50V Capacitor, 27p, 0402, NP0, 5%, 50V Capacitor, 1n, 0402, NP0, 5%, 50V 0402 Capacitor
0402 Capacitor
0402 Capacitor
Capacitor, 100n, 0402, X5R, 10%, 10V 0402 Capacitor
0402 Capacitor
Capacitor, 1u0, 0603, X5R, 10%, 6.3V Capacitor, 2u2, 0402, X5R, 20%, 4V 0402 Capacitor
LEDs
LEDs
LEDs
LEDs

Inductor, 1n0, 0402, Monolithic type, +/-0.3 nH Inductor, 1n1, 0402, Monolithic type, +/-0.3 nH Inductor, 1n5, 0402, wire-wound type, +/-0.1 nH Inductor, 2n0, 0402, +/-0.3 nH
Inductor, 5n1, 0402, +/-0.3 nH

EMI filter bead, 0402 1Kohms GHz Band Gen Use EMI filter bead, 0603 1Kohms GHz Band Gen Use 2x23 Pin Header
RESISTOR, American symbol
RESISTOR, American symbol
RESISTOR, American symbol
RESISTOR, American symbol
RESISTOR, American symbol
RESISTOR, American symbol
Resistor
RESISTOR, American symbol
RESISTOR, American symbol
RESISTOR, American symbol
0.040in Test Point
2.4 GHZ IEEE 802.15.4/ZIGBEE® RF TRANSCEIVER 256kb Serial CMOS EEPROM
2.4GHz Range Extender
IC MUX/DEMUX 8x1 16TSSOP

Multiprotocol Bluetooth® 4.0 low energy/2.4 GHz RF SoC 32kB/256kB CRYSTAL 32MHZ 10PF SMD
2mmx1.6mm SMD Crystal
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

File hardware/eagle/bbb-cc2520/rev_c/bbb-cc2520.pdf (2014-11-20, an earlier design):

1 BeagleBone Black Header GND0 P9_1; GND1; P9_4 VDD_5V0 P9_5; VDD_5V1; P9_6 SYS_5V0 P9_7; SYS_5V1; P9_8 PWR_BUT P9_9; SYS_RESETN; P9_10 UART4_RXD P9_11; GPIO1_28; P9_12 UART4_TXD P9_13; EHRPWM1A; P9_14 GPIO1_16 P9_15; EHRPWM1B; P9_16 I2C1_SCL P9_17; I2C1_SDA; P9_18 I2C2_SCL P9_19; I2C2_SDA; P9_20 UART2_TXD P9_21; UART2_RXD; P9_22 GPIO1_17 P9_23; UART1_TXD; P9_24 GPIO3_21 P9_25; UART1_RXD; P9_26 GPIO3_19 P9_27; SPI1_CS0; P9_28 SPI1_D0 P9_29; SPI1_D1; P9_30 SPI1_SCLK P9_31; VADC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

# CC2520. Index: 0, no amplifier


14
16

# CC2520. Index: 1, with amplifier


14
16

# nRF51822


# Chip Select DeMux

# EEPROM



Top and Bottom Layers

Top Layer

Bottom Layer


Top Copper Layer


Bottom Copper Layer

Top; Paste Layer with Silkscreen


Bottom Paste Layer with Silkscreen


Top and Bottom Layers 1:1 Scale


Top Layer 1:1 Scale


Bottom Copper Layer 1:1 Scale

Qty | Value | Device
| 3 MOLEX_WM5544-ND | MOLEX_WM5544-ND
| 12450BM15A0002 | 2450BM15A0002
| 1 BAL-NRF01D3 | BAL-NRF01D3
| 10.8pF | CAPACITOR
| 11pF | C-EUC0402
| 12.7pF | C-EUC0402
| 13pF | C-EUC0402
| 13.9pF | C-EUC0402
| 16.8pF | C-EUC0402
| 212pF | CAPACITOR
| 115pF | C-EUC0402
| 427pF | C-EUC0402
| 31nF | C-EUC0402
| 21nF | CAPACITOR
| 12.2nF | CAPACITOR
| 147nF | CAPACITOR
| 9100nF | C-EUC0402
| 10.1uF | CAPACITOR
| 11uF | CAPACITOR
| 21uF | C-EUC0603
| 12.2uF | C-EUC0402
| 14.7uF | CAPACITOR
| 1 GREEN | LED0603
| 1 RED | LED0603
| 1 BLUE | LED0603
| 1 YELLOW | LED0603
| 1 JUMPER-PTH-2-NO | JUMPER-PTH-2-NO
| 41nH | INDUCTOR0402
| 11.1nH | INDUCTOR0402
| 11.5nH | INDUCTOR0402
| 12nH | INDUCTOR0402
| 15.1nH | INDUCTOR0402
| 115nH | INDUCTOR0402
| 110uH | INDUCTOR0603
| 11k Ohm | INDUCTOR0402
| 21k Ohm | INDUCTOR0603
| 2 BBB_HEADERS | BBB_HEADERS
| 3470 ohm | R-US_R0402
| 21k 1% | R-US_R0402
| 14.3k | R-US_R0402
| 34.75k | R-US_R0402
| 25.6k 5% | R-US_R0402
| 110k 1% | R-US_R0402
| 112k | RESISTOR
| 256k 1% | R-US_R0402
| 1330k 1% | R-US_R0402
| 21M 1% | R-US_R0402

### 3 TEST_POINT_0.040IN TEST_POINT_0.040IN

| 2 CC2520 | CC2520
| 1 CAT24C256WI-GT3 | CAT24C256WI-GT3
| 1 CC2591 | CC2591
| 1 CD4051B-53B | CD4051B-53B
| 1 NRF51822QF | NRF51822QF
| 2 NX2520SA | NX2520SA
| 116MHz | TXC-8Y

Parts
ANT1, ANT2, ANT3
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
C7, C8
C9
C10, C11, C12, C13
C14, C15, C16
C17, C18
C19
C20
C21, C22, C23, C24, C25, C26, C27, C28, C29 C30
C31
C32, C33
C34
C35
D1
D2
D3
D4
J2
L1, L2, L3, L4
L5
L6
L7
L8
L9
L10
L11
L12, L13
P8, P9
R1, R2, R3, R4
R5, R6
R7
R8, R9, R10
R11, R12
R13, R14, R15, R16
R17
R18, R19
R20
R21, R22

### TP0, TP1, TP2

U1, U2
U3
U4
U5
U6
X1, X2
X3

Description
Through-hole SMA Antenna
BALUN JTI MATCHED ZIGBEE
50 ohm nominal input / conjugate match balun to nRF51422-QFAA, 0402 Capacitor
Capacitor, 1p, 0402, NP0, +/-0.1pF 50V
Capacitor, 2p7, 0402, NP0, +-0.25pF, 50V
Capacitor, 3p, 0402, NP0, +-0.25pF, 50V Capacitor, 3p9, 0402, NP0, +-0.25pF, 50V Capacitor, 6p8, 0402, NP0, +-0.25pF 50V 0402 Capacitor
Capacitor, 15p, 0402, NP0, 5%, 50V Capacitor, 27p, 0402, NP0, 5%, 50V Capacitor, 1n, 0402, NP0, 5%, 50V 0402 Capacitor
0402 Capacitor
0402 Capacitor
Capacitor, 100n, 0402, X5R, 10%, 10V 0402 Capacitor
0402 Capacitor
Capacitor, 1u0, 0402, X5R, 10%, 6.3V Capacitor, 2u2, 0402, X5R, 20%, 4V 0402 Capacitor
LEDs
LEDs
LEDs
LEDs

Inductor, 1n0, 0402, Monolithic type, +/-0.3 nH Inductor, 1n1, 0402, Monolithic type, +/-0.3 nH Inductor, 1n5, 0402, wire-wound type, +/-0.1 nH Inductor, 2n0, 0402, +/-0.3 nH
Inductor, 5n1, 0402, +/-0.3 nH

EMI filter bead, 0402 1Kohms GHz Band Gen Use EMI filter bead, 0603 1Kohms GHz Band Gen Use 2x23 Pin Header
RESISTOR, American symbol
RESISTOR, American symbol
RESISTOR, American symbol
RESISTOR, American symbol
RESISTOR, American symbol
RESISTOR, American symbol
Resistor
RESISTOR, American symbol
RESISTOR, American symbol
RESISTOR, American symbol
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

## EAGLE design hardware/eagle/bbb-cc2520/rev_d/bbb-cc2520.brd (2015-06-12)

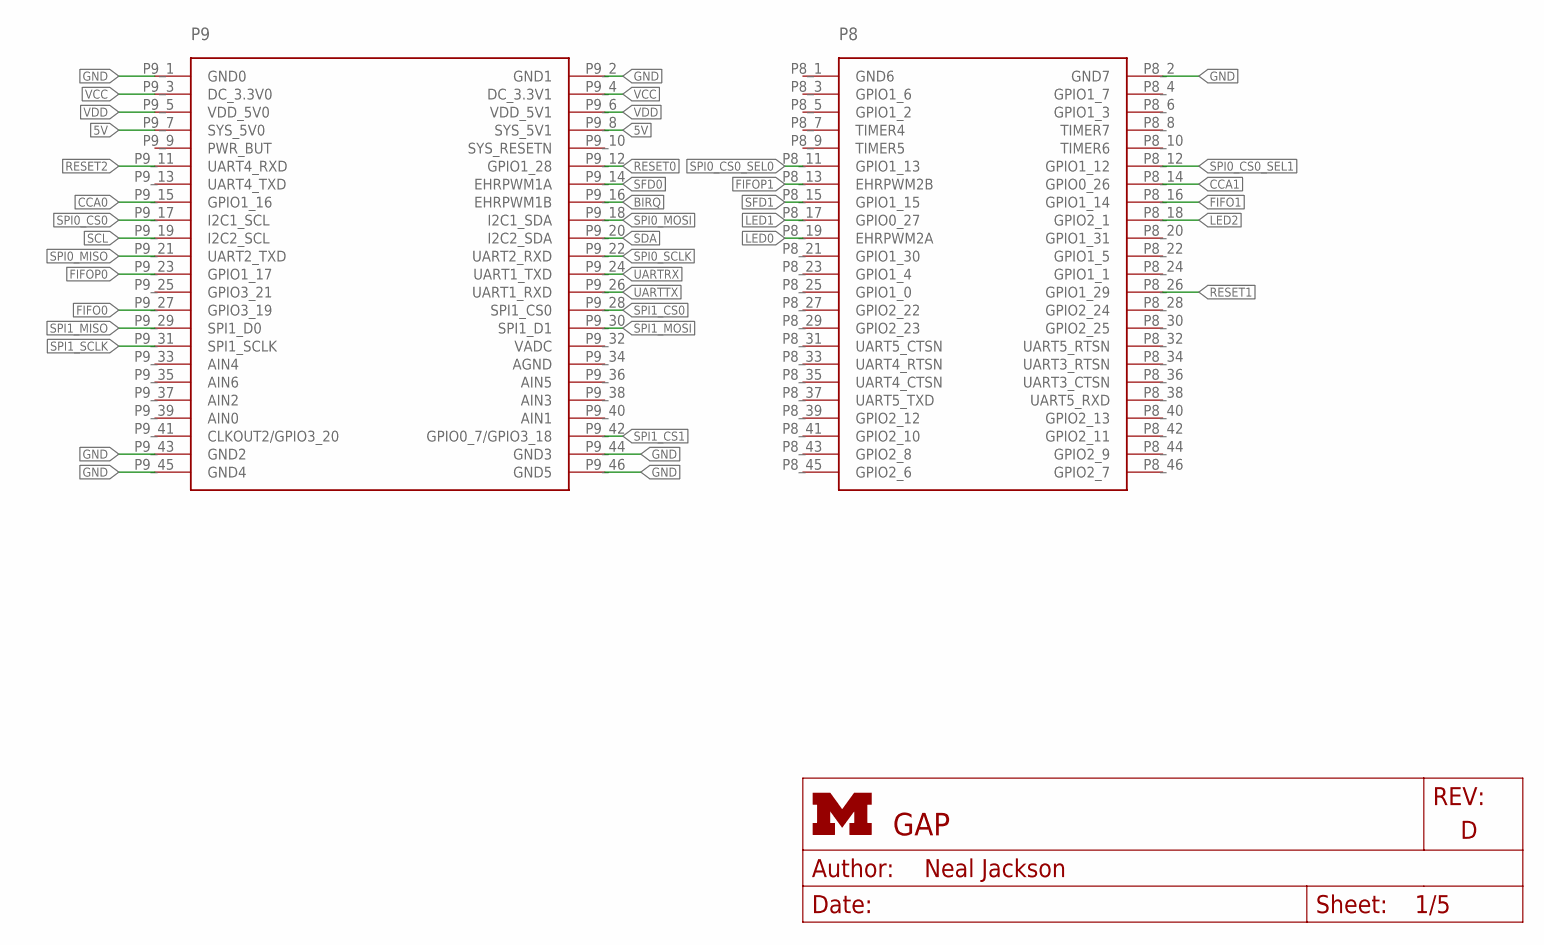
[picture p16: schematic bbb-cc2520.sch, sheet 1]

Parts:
P9/P8: BBB_HEADERS

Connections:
5V: P9/P8.P9_7 (SYS_5V0), P9/P8.P9_8 (SYS_5V1)
!RESET0: P9/P8.P9_12 (GPIO1_28); also elsewhere on the board
!RESET1: P9/P8.P8_26 (GPIO1_29); also elsewhere on the board
!RESET2: P9/P8.P9_11 (UART4_RXD); also elsewhere on the board
BIRQ: P9/P8.P9_16 (EHRPWM1B); also elsewhere on the board
CCA0: P9/P8.P9_15 (GPIO1_16); also elsewhere on the board
CCA1: P9/P8.P8_14 (GPIO0_26); also elsewhere on the board
FIFO0: P9/P8.P9_27 (GPIO3_19); also elsewhere on the board
FIFO1: P9/P8.P8_16 (GPIO1_14); also elsewhere on the board
FIFOP0: P9/P8.P9_23 (GPIO1_17); also elsewhere on the board
FIFOP1: P9/P8.P8_13 (EHRPWM2B); also elsewhere on the board
GND: P9/P8.P8_2 (GND7), P9/P8.P9_1 (GND0), P9/P8.P9_2 (GND1), P9/P8.P9_43 (GND2), P9/P8.P9_44 (GND3), P9/P8.P9_45 (GND4), P9/P8.P9_46 (GND5); also elsewhere on the board
LED0: P9/P8.P8_19 (EHRPWM2A); also elsewhere on the board
LED1: P9/P8.P8_17 (GPIO0_27); also elsewhere on the board
LED2: P9/P8.P8_18 (GPIO2_1); also elsewhere on the board
SCL: P9/P8.P9_19 (I2C2_SCL); also elsewhere on the board
SDA: P9/P8.P9_20 (I2C2_SDA); also elsewhere on the board
SFD0: P9/P8.P9_14 (EHRPWM1A); also elsewhere on the board
SFD1: P9/P8.P8_15 (GPIO1_15); also elsewhere on the board
SPI0_CS0: P9/P8.P9_17 (I2C1_SCL); also elsewhere on the board
SPI0_CS0_SEL0: P9/P8.P8_11 (GPIO1_13); also elsewhere on the board
SPI0_CS0_SEL1: P9/P8.P8_12 (GPIO1_12); also elsewhere on the board
SPI0_MISO: P9/P8.P9_21 (UART2_TXD); also elsewhere on the board
SPI0_MOSI: P9/P8.P9_18 (I2C1_SDA); also elsewhere on the board
SPI0_SCLK: P9/P8.P9_22 (UART2_RXD); also elsewhere on the board
SPI1_CS0: P9/P8.P9_28 (SPI1_CS0); also elsewhere on the board
SPI1_CS1: P9/P8.P9_42 (GPIO0_7/GPIO3_18); also elsewhere on the board
SPI1_MISO: P9/P8.P9_29 (SPI1_D0); also elsewhere on the board
SPI1_MOSI: P9/P8.P9_30 (SPI1_D1); also elsewhere on the board
SPI1_SCLK: P9/P8.P9_31 (SPI1_SCLK); also elsewhere on the board
UARTRX: P9/P8.P9_24 (UART1_TXD); also elsewhere on the board
UARTTX: P9/P8.P9_26 (UART1_RXD); also elsewhere on the board
VCC: P9/P8.P9_3 (DC_3.3V0), P9/P8.P9_4 (DC_3.3V1); also elsewhere on the board
VDD: P9/P8.P9_5 (VDD_5V0), P9/P8.P9_6 (VDD_5V1)

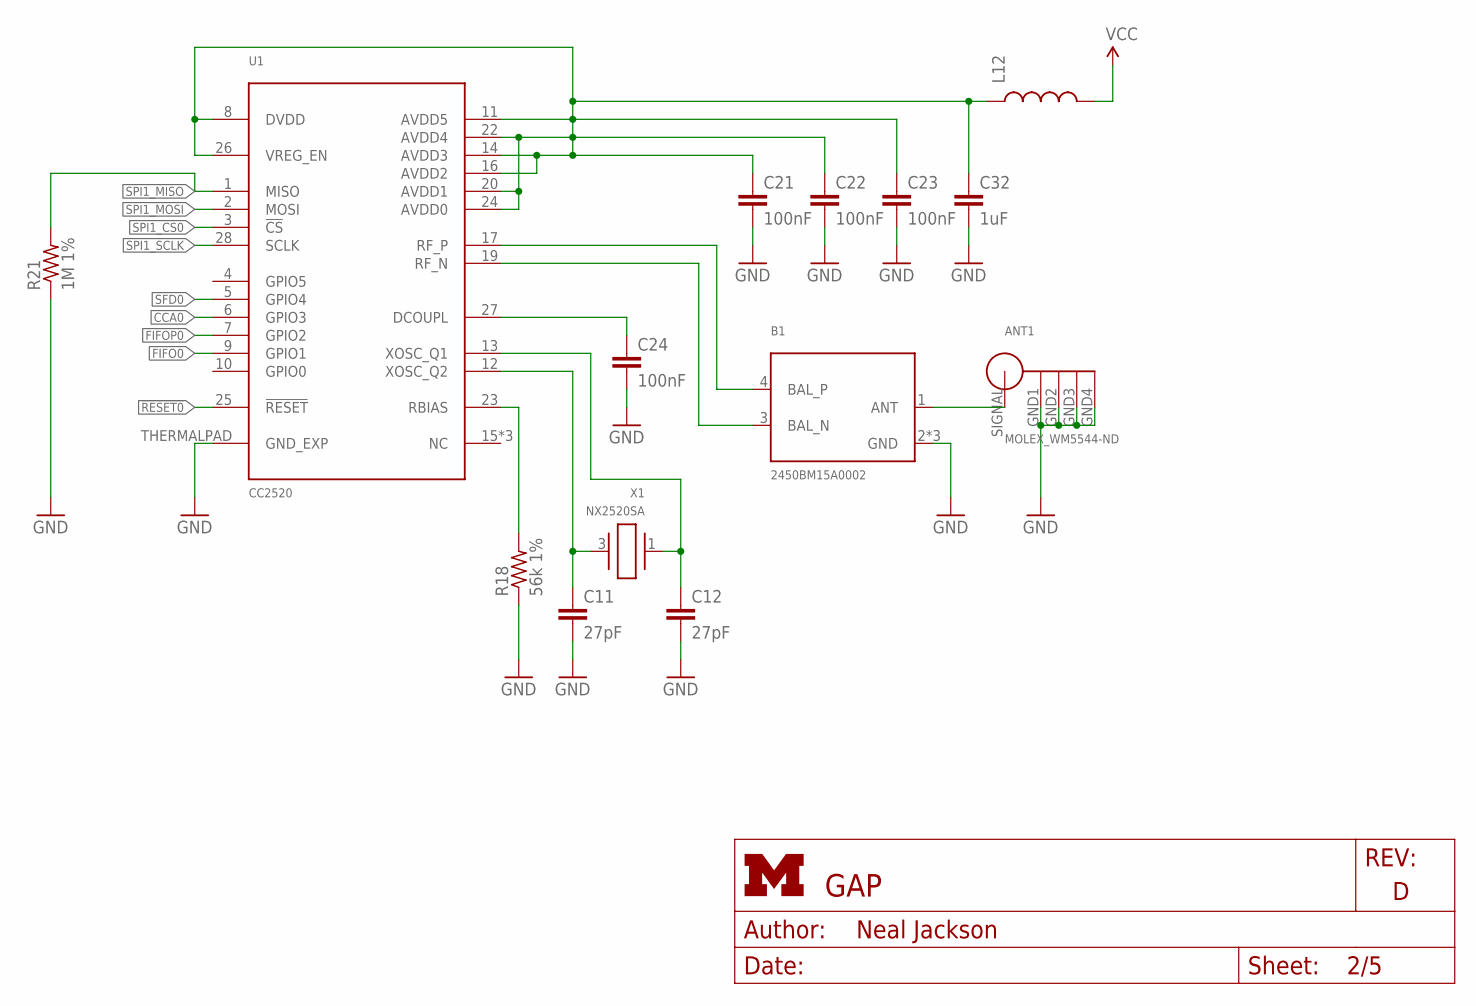
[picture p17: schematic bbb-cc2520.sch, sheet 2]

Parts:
ANT1: MOLEX_WM5544-ND
B1: 2450BM15A0002; 2450BM
C11, C12: 27pF; C0402; DIGIKEY 490-5869-1-ND
C21, C22, C23, C24: 100nF; C0402; DIGIKEY 490-1318-1-ND
C32: 1uF; C0603; DIGIKEY 490-1550-1-ND
L12: INDUCTOR0603; 0603; DIGIKEY 490-1015-1-ND
R18: 56k 1%; R0402; DIGIKEY P56.0KLCT-ND
R21: 1M 1%; R0402; DIGIKEY RHM1.00MCDCT-ND
U1: CC2520; S-PVQFN-N28
X1: NX2520SA

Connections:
!RESET0: U1.25 (!RESET); also elsewhere on the board
CCA0: U1.6 (GPIO3); also elsewhere on the board
FIFO0: U1.9 (GPIO1); also elsewhere on the board
FIFOP0: U1.7 (GPIO2); also elsewhere on the board
GND: ANT1.GND1, ANT1.GND2, ANT1.GND3, ANT1.GND4, B1.2 (GND), B1.5 (GND), B1.6 (GND), C11.2, C12.2, C21.2, C22.2, C23.2, C24.2, C32.2, R18.1, R21.1, U1.THERMALPAD (GND_EXP); also elsewhere on the board
unnamed: C21.1, C22.1, C23.1, C32.1, L12.1, U1.8 (DVDD), U1.11 (AVDD5), U1.14 (AVDD3), U1.16 (AVDD2), U1.20 (AVDD1), U1.22 (AVDD4), U1.24 (AVDD0), U1.26 (VREG_EN)
unnamed: ANT1.SIGNAL, B1.1 (ANT)
unnamed: C12.1, U1.13 (XOSC_Q1), X1.1
unnamed: C24.1, U1.27 (DCOUPL)
unnamed: C11.1, U1.12 (XOSC_Q2), X1.3 (2)
unnamed: R18.2, U1.23 (RBIAS)
RF_N: B1.3 (BAL_N), U1.19 (RF_N)
RF_P: B1.4 (BAL_P), U1.17 (RF_P)
SFD0: U1.5 (GPIO4); also elsewhere on the board
SPI1_CS0: U1.3 (!CS); also elsewhere on the board
SPI1_MISO: R21.2, U1.1 (MISO); also elsewhere on the board
SPI1_MOSI: U1.2 (MOSI); also elsewhere on the board
SPI1_SCLK: U1.28 (SCLK); also elsewhere on the board
VCC: L12.2; also elsewhere on the board

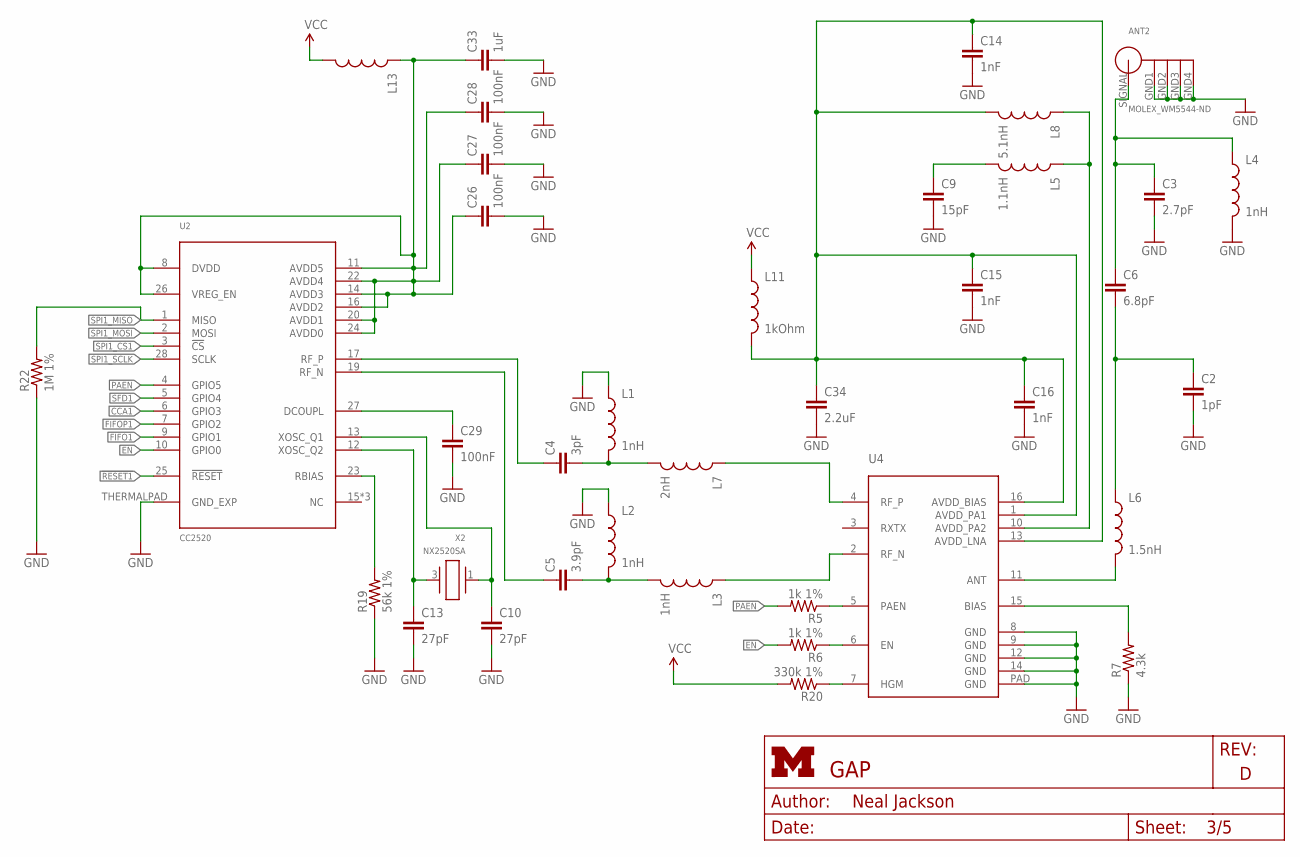
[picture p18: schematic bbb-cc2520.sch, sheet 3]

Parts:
ANT2: MOLEX_WM5544-ND
C2: 1pF; C0402; DIGIKEY 490-1318-1-ND
C3: 2.7pF; C0402; DIGIKEY 490-1318-1-ND
C4: 3pF; C0402; DIGIKEY 490-1318-1-ND
C5: 3.9pF; C0402; DIGIKEY 490-1318-1-ND
C6: 6.8pF; C0402; DIGIKEY 490-1318-1-ND
C9: 15pF; C0402; DIGIKEY 490-1318-1-ND
C10, C13: 27pF; C0402; DIGIKEY 490-5869-1-ND
C14, C15, C16: 1nF; C0402; DIGIKEY 490-1318-1-ND
C26, C27, C28, C29: 100nF; C0402; DIGIKEY 490-1318-1-ND
C33: 1uF; C0603; DIGIKEY 490-1550-1-ND
C34: 2.2uF; C0402; DIGIKEY 490-1318-1-ND
L1, L2, L3, L4: 1nH; C0402
L5: 1.1nH; C0402
L6: 1.5nH; C0402
L7: 2nH; C0402
L8: 5.1nH; C0402
L11: 1kOhm; C0402
L13: INDUCTOR0603; 0603; DIGIKEY 490-1015-1-ND
R5, R6: 1k 1%; R0402; DIGIKEY P56.0KLCT-ND
R7: 4.3k; R0402; DIGIKEY P56.0KLCT-ND
R19: 56k 1%; R0402; DIGIKEY P56.0KLCT-ND
R20: 330k 1%; R0402; DIGIKEY P56.0KLCT-ND
R22: 1M 1%; R0402; DIGIKEY RHM1.00MCDCT-ND
U2: CC2520; S-PVQFN-N28
U4: CC2591; PVQFN-16
X2: NX2520SA

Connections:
!RESET1: U2.25 (!RESET); also elsewhere on the board
CCA1: U2.6 (GPIO3); also elsewhere on the board
EN: R6.2, U2.10 (GPIO0)
FIFO1: U2.9 (GPIO1); also elsewhere on the board
FIFOP1: U2.7 (GPIO2); also elsewhere on the board
GND: ANT2.GND1, ANT2.GND2, ANT2.GND3, ANT2.GND4, C2.2, C3.2, C9.2, C10.2, C13.2, C14.2, C15.2, C16.2, C26.2, C27.2, C28.2, C29.2, C33.2, C34.2, L1.1, L2.1, L4.2, R7.1, R19.1, R22.1, U2.THERMALPAD (GND_EXP), U4.8 (GND), U4.9 (GND), U4.12 (GND), U4.14 (GND), U4.PAD (GND); also elsewhere on the board
unnamed: L7.1, U4.4 (RF_P)
unnamed: L3.1, U4.2 (RF_N)
unnamed: C5.2, L2.2, L3.2
unnamed: C4.2, L1.2, L7.2
unnamed: L5.1, L8.1, U4.10 (AVDD_PA2)
unnamed: C14.1, C15.1, C16.1, C34.1, L8.2, L11.2, U4.1 (AVDD_PA1), U4.13 (AVDD_LNA), U4.16 (AVDD_BIAS)
unnamed: C9.1, L5.2
unnamed: L6.2, U4.11 (ANT)
unnamed: ANT2.SIGNAL, C3.1, C6.1, L4.1
unnamed: C2.1, C6.2, L6.1
unnamed: R7.2, U4.15 (BIAS)
unnamed: R5.1, U4.5 (PAEN)
unnamed: R6.1, U4.6 (EN)
unnamed: C26.1, C27.1, C28.1, C33.1, L13.1, U2.8 (DVDD), U2.11 (AVDD5), U2.14 (AVDD3), U2.16 (AVDD2), U2.20 (AVDD1), U2.22 (AVDD4), U2.24 (AVDD0), U2.26 (VREG_EN)
unnamed: C29.1, U2.27 (DCOUPL)
unnamed: C10.1, U2.13 (XOSC_Q1), X2.1
unnamed: C13.1, U2.12 (XOSC_Q2), X2.3 (2)
unnamed: R19.2, U2.23 (RBIAS)
unnamed: R20.1, U4.7 (HGM)
PAEN: R5.2, U2.4 (GPIO5)
RF_N2: C5.1, U2.19 (RF_N)
RF_P2: C4.1, U2.17 (RF_P)
SFD1: U2.5 (GPIO4); also elsewhere on the board
SPI1_CS1: U2.3 (!CS); also elsewhere on the board
SPI1_MISO: R22.2, U2.1 (MISO); also elsewhere on the board
SPI1_MOSI: U2.2 (MOSI); also elsewhere on the board
SPI1_SCLK: U2.28 (SCLK); also elsewhere on the board
VCC: L11.1, L13.2, R20.2; also elsewhere on the board

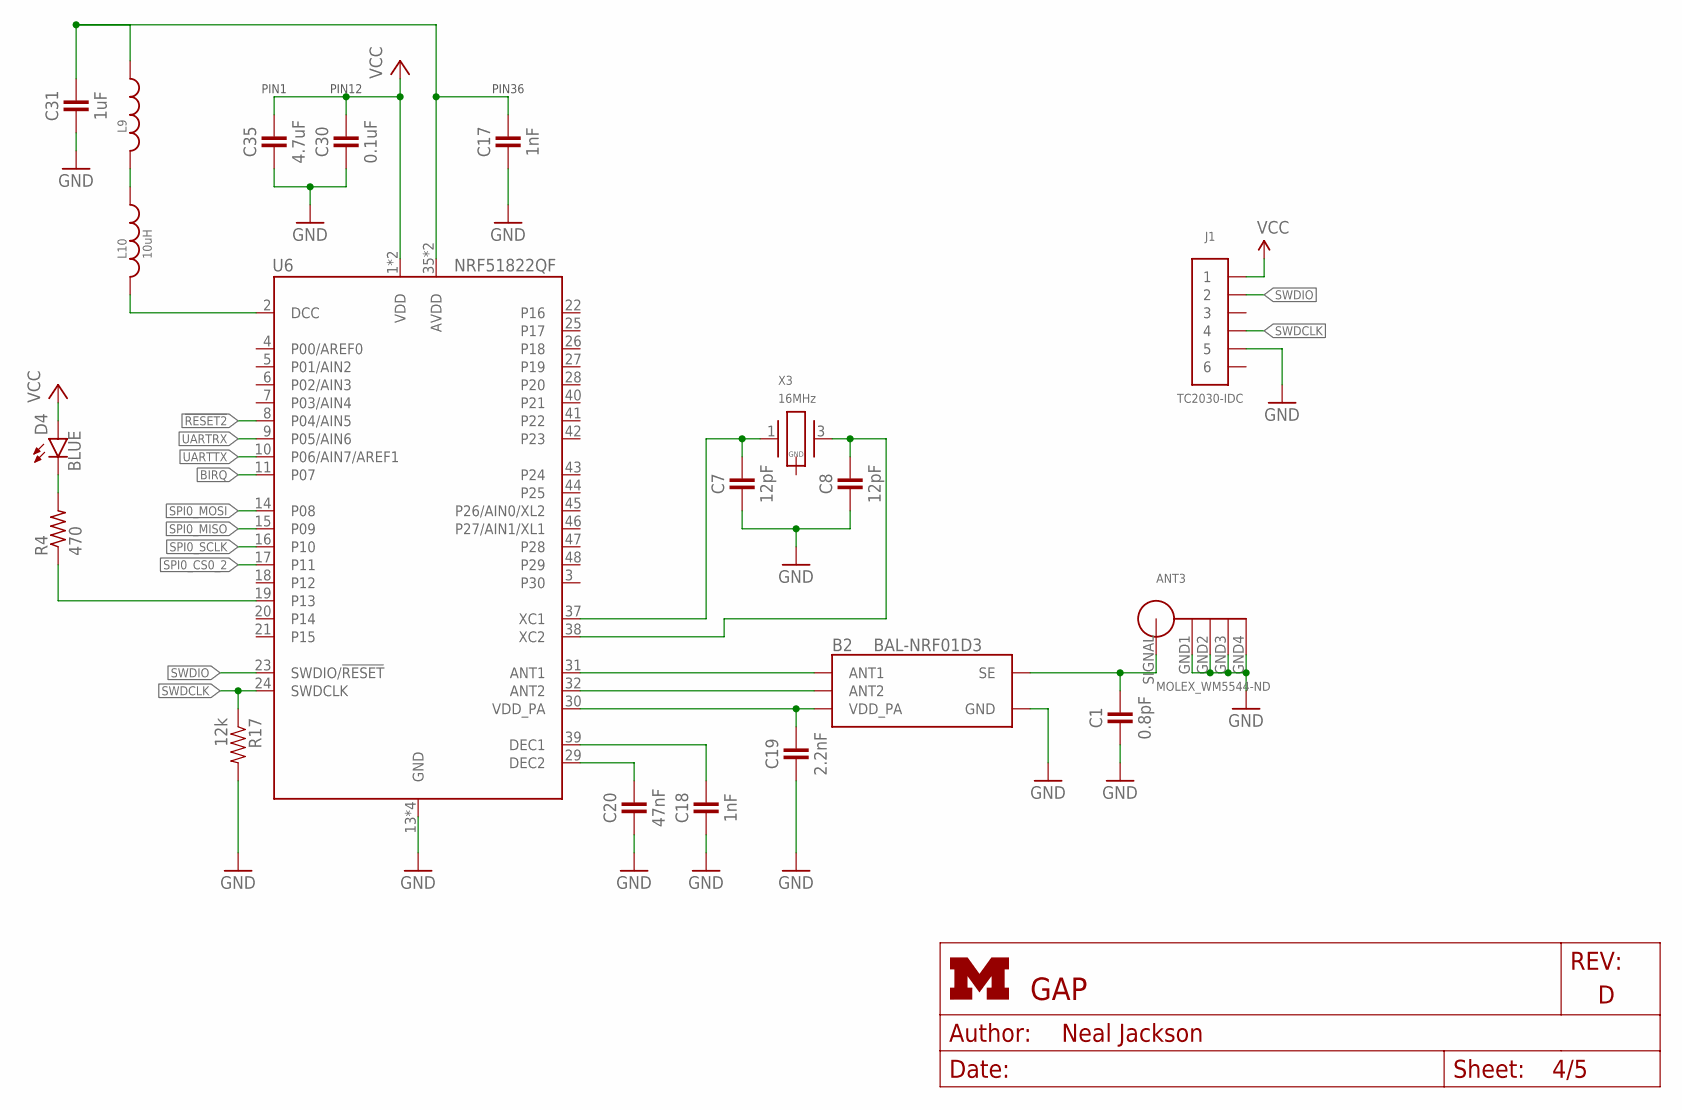
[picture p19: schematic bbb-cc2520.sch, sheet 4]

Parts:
ANT3: MOLEX_WM5544-ND
B2: BAL-NRF01D3
C1: 0.8pF; 0402_CAP; DIGIKEY 490-5419-1-ND
C7, C8: 12pF; 0402_CAP; DIGIKEY 490-6197-1-ND
C17, C18: 1nF; 0402_CAP; DIGIKEY 490-1303-1-ND
C19: 2.2nF; 0402_CAP; DIGIKEY 490-5419-1-ND
C20: 47nF; 0402_CAP; DIGIKEY 445-1264-1-ND
C30: 0.1uF; 0402_CAP; DIGIKEY 445-4952-1-ND
C31: 1uF; 0402_CAP; DIGIKEY 1276-1513-1-ND
C35: 4.7uF; 0402_CAP; DIGIKEY 445-5947-1-ND
D4: BLUE; LED-0603
J1: TC2030-IDC
L9: INDUCTOR0402; 0402_CAP; DIGIKEY 587-1521-1-ND
L10: 10uH; 0603_CAP; DIGIKEY 490-4025-1-ND
R4: 470; R0402; DIGIKEY RHM470JCT-ND
R17: 12k; 0603-RES; DIGIKEY RHM12.0KCDCT-ND
U6: NRF51822QF; QFN-48-6MM
X3: 16MHz; TXC-8Y; DIGIKEY 887-2003-1-ND

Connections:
!RESET2: U6.8 (P04/AIN5); also elsewhere on the board
AVDD: C17.1, C31.1, L9.1, U6.35 (AVDD), U6.36 (AVDD)
BIRQ: U6.11 (P07); also elsewhere on the board
DCC: L10.2, U6.2 (DCC)
GND: ANT3.GND1, ANT3.GND2, ANT3.GND3, ANT3.GND4, B2.GND, C1.2, C7.2, C8.2, C17.2, C18.2, C19.2, C20.2, C30.2, C31.2, C35.2, J1.5, R17.2, U6.13 (GND), U6.33 (GND), U6.34 (GND), U6.GND; also elsewhere on the board
unnamed: B2.ANT1, U6.31 (ANT1)
unnamed: B2.ANT2, U6.32 (ANT2)
unnamed: ANT3.SIGNAL, B2.SE, C1.1
unnamed: L9.2, L10.1
unnamed: C7.1, U6.37 (XC1), X3.1
unnamed: C8.1, U6.38 (XC2), X3.3 (2)
unnamed: C18.1, U6.39 (DEC1)
unnamed: C20.1, U6.29 (DEC2)
unnamed: D4.C, R4.2
unnamed: R4.1, U6.19 (P13)
SPI0_CS0_2: U6.17 (P11); also elsewhere on the board
SPI0_MISO: U6.15 (P09); also elsewhere on the board
SPI0_MOSI: U6.14 (P08); also elsewhere on the board
SPI0_SCLK: U6.16 (P10); also elsewhere on the board
SWDCLK: J1.4, R17.1, U6.24 (SWDCLK)
SWDIO: J1.2, U6.23 (SWDIO/!RESET)
UARTRX: U6.9 (P05/AIN6); also elsewhere on the board
UARTTX: U6.10 (P06/AIN7/AREF1); also elsewhere on the board
VCC: C30.1, C35.1, D4.A, J1.1, U6.1 (VDD), U6.12 (VDD); also elsewhere on the board
VDD_PA: B2.VCC (VDD_PA), C19.1, U6.30 (VDD_PA)

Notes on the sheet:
PIN12
PIN1
PIN36

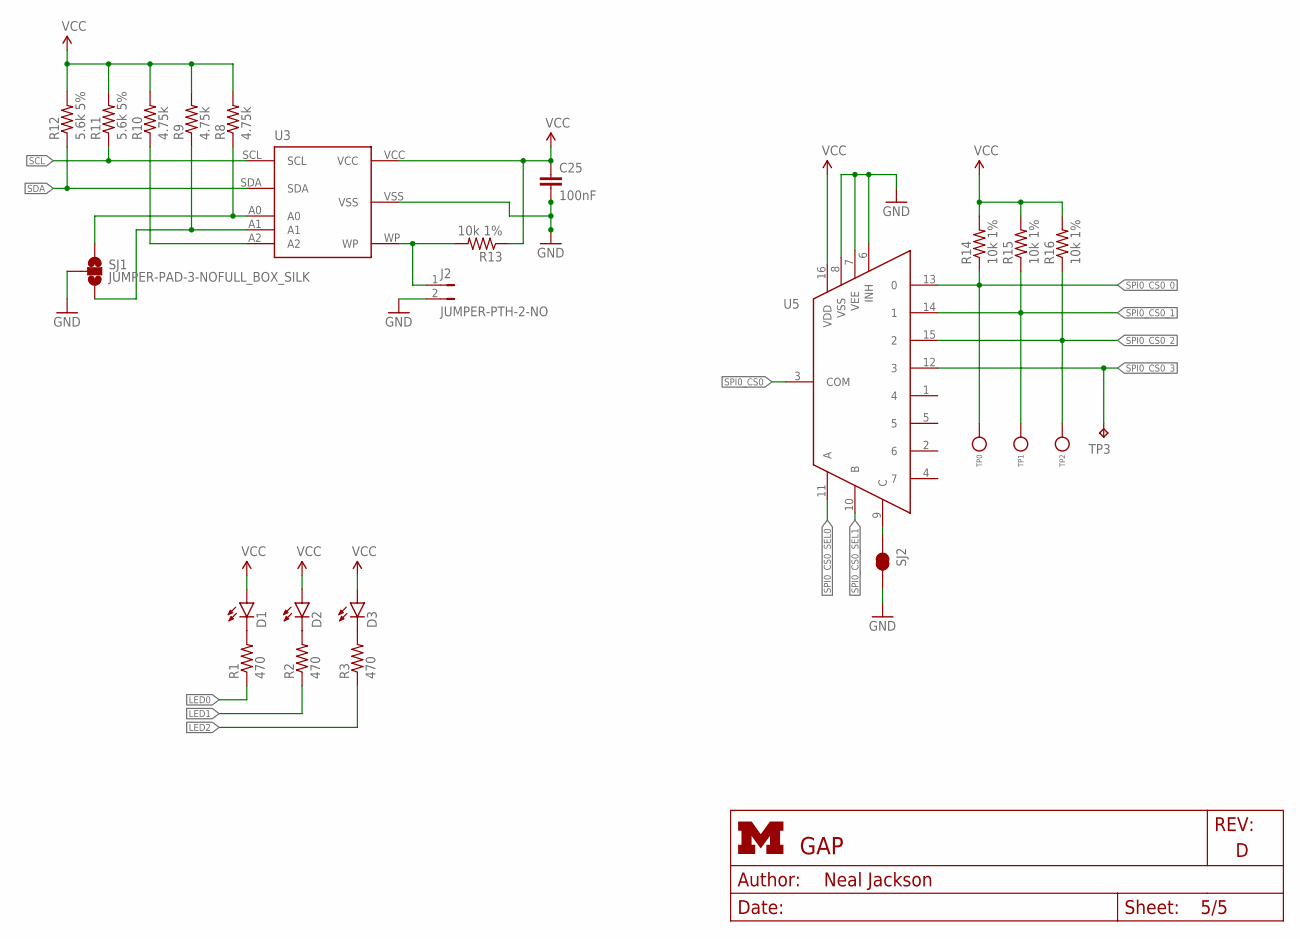
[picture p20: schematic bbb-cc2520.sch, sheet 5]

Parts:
C25: 100nF; C0402; DIGIKEY 490-1318-1-ND
D1: LED0603; LED-0603; DIGIKEY 160-1834-1-ND
D2: LED0603; LED-0603; DIGIKEY 160-1835-1-ND
D3: LED0603; LED-0603; DIGIKEY 160-1837-1-ND
J2: JUMPER-PTH-2-NO; PTH-JUMPER-2-NO_NO_SILK
R1, R2, R3: 470; R0402; DIGIKEY RHM470JCT-ND
R8, R9, R10: 4.75k; R0402; DIGIKEY RHM1.00MCDCT-ND
R11, R12: 5.6k 5%; R0402; DIGIKEY RHM1.00MCDCT-ND
R13, R14, R15, R16: 10k 1%; R0402; DIGIKEY RHM1.00MCDCT-ND
SJ1: JUMPER-PAD-3-NOFULL_BOX_SILK; PAD-JUMPER-3-NO_YES_SILK_FULL_BOX
SJ2: JUMPER-PAD-2-NC_BY_TRACE; PAD-JUMPER-2-NC_BY_TRACE_YES_SILK
TP0, TP1, TP2: TEST_POINT_0.040IN; TESTPOINT_0.040IN
TP3: TPTP14SQ; TP14SQ
U3: CAT24C256WI-GT3
U5: CD4051B-53B; TSSOP16

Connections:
GND: C25.2, J2.2, SJ1.2, SJ2.2, U3.VSS, U5.6 (INH), U5.7 (VEE), U5.8 (VSS); also elsewhere on the board
LED0: R1.1; also elsewhere on the board
LED1: R2.1; also elsewhere on the board
LED2: R3.1; also elsewhere on the board
unnamed: D1.C, R1.2
unnamed: D2.C, R2.2
unnamed: D3.C, R3.2
unnamed: R8.1, SJ1.1, U3.A0
unnamed: R9.1, SJ1.3, U3.A1
unnamed: J2.1, R13.2, U3.WP
unnamed: R10.1, U3.A2
unnamed: SJ2.1, U5.9 (C)
SCL: R11.1, U3.SCL; also elsewhere on the board
SDA: R12.1, U3.SDA; also elsewhere on the board
SPI0_CS0: U5.3 (COM); also elsewhere on the board
SPI0_CS0_0: R14.1, TP0.TESTPOINT, U5.13 (0)
SPI0_CS0_1: R15.1, TP1.TESTPOINT, U5.14 (1)
SPI0_CS0_2: R16.1, TP2.TESTPOINT, U5.15 (2); also elsewhere on the board
SPI0_CS0_3: TP3.TP, U5.12 (3)
SPI0_CS0_SEL0: U5.11 (A); also elsewhere on the board
SPI0_CS0_SEL1: U5.10 (B); also elsewhere on the board
VCC: C25.1, D1.A, D2.A, D3.A, R8.2, R9.2, R10.2, R11.2, R12.2, R13.1, R14.2, R15.2, R16.2, U3.VCC, U5.16 (VDD); also elsewhere on the board

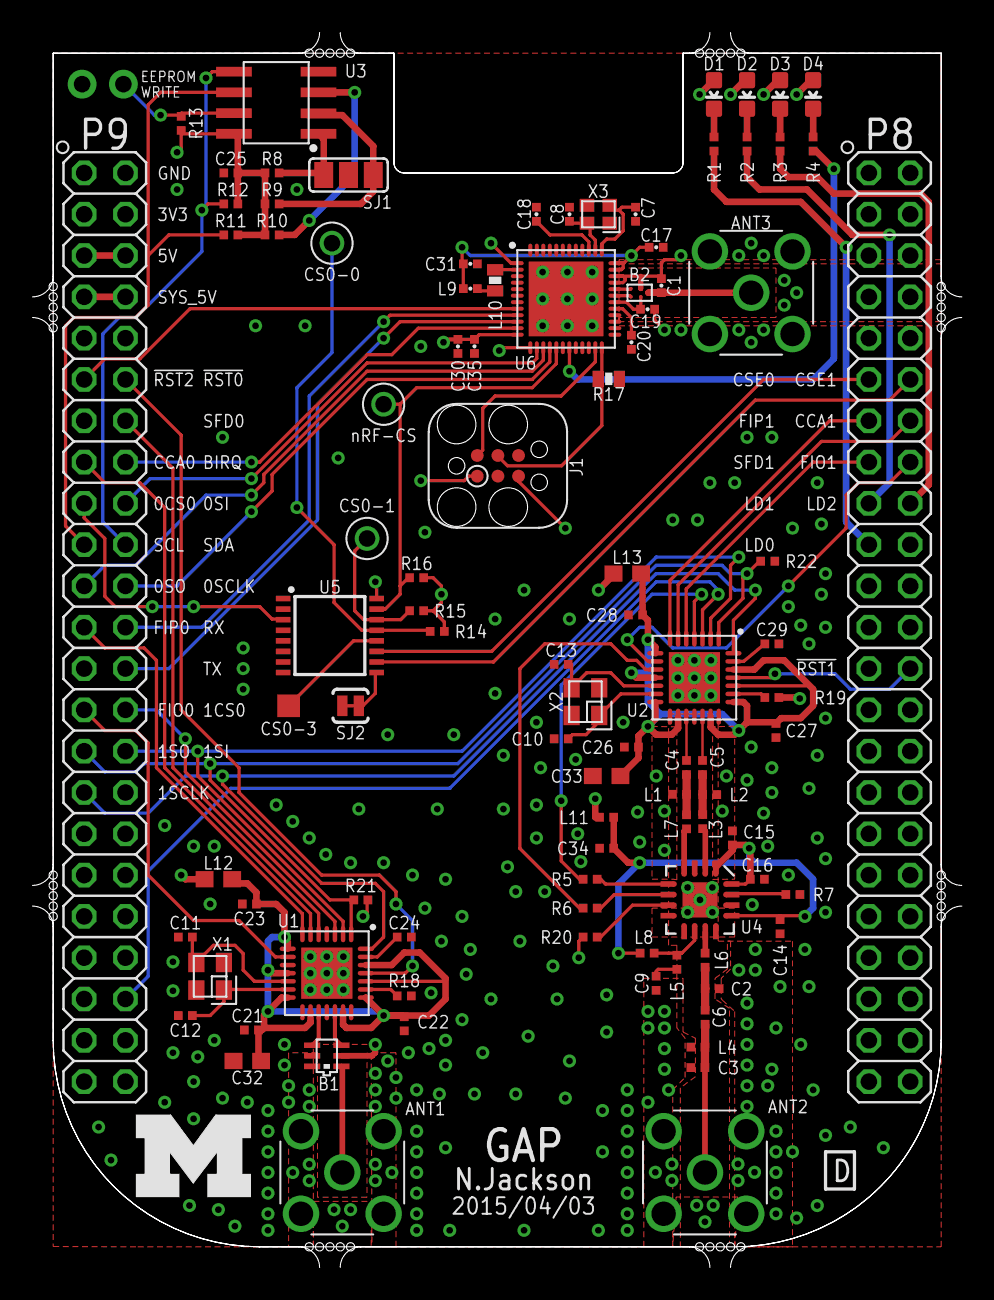
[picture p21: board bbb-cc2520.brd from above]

Board: 4 copper layers, 57.2 x 75.9 mm, 98 parts (0 on the bottom side), 92 nets.

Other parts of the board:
U$2: UMICH_SOLID_200MIL

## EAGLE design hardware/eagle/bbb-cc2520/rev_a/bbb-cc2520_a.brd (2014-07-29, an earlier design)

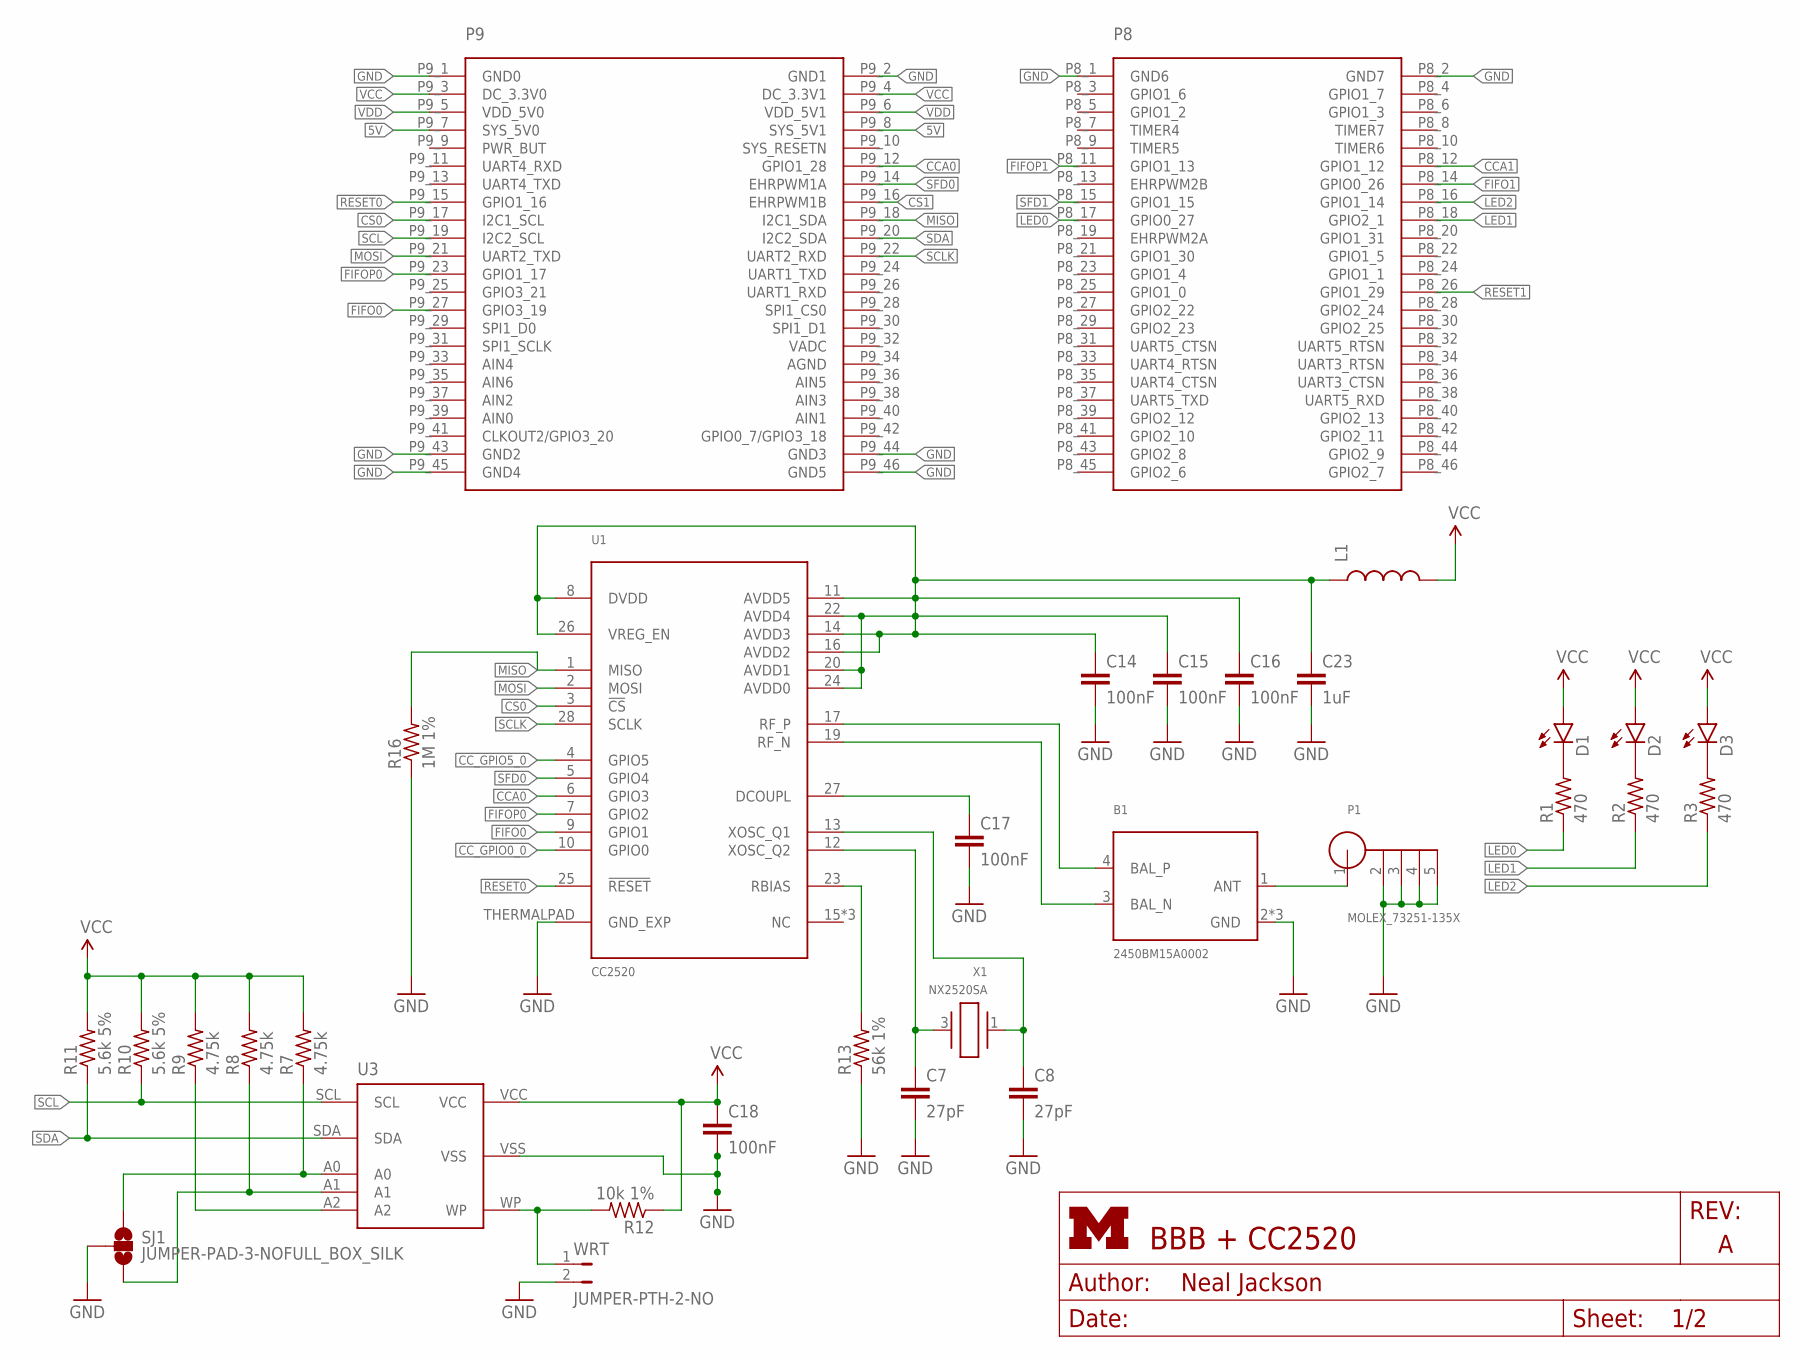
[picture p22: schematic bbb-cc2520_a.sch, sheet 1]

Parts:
B1: 2450BM15A0002; 2450BM
C7, C8: 27pF; C0402; DIGIKEY 490-5869-1-ND
C14, C15, C16, C17, C18: 100nF; C0402; DIGIKEY 490-1318-1-ND
C23: 1uF; C0603; DIGIKEY 490-1550-1-ND
D1: LED0603; LED-0603; DIGIKEY 160-1834-1-ND
D2: LED0603; LED-0603; DIGIKEY 160-1835-1-ND
D3: LED0603; LED-0603; DIGIKEY 160-1837-1-ND
L1: INDUCTOR0603; 0603; DIGIKEY 490-1015-1-ND
P1: MOLEX_73251-135X; SMA-J/PCB
P9/P8: BBB_HEADERS
R1, R2, R3: 470; R0402; DIGIKEY RHM470JCT-ND
R7, R8, R9: 4.75k; R0402; DIGIKEY RHM1.00MCDCT-ND
R10, R11: 5.6k 5%; R0402; DIGIKEY RHM1.00MCDCT-ND
R12: 10k 1%; R0402; DIGIKEY RHM1.00MCDCT-ND
R13: 56k 1%; R0402; DIGIKEY P56.0KLCT-ND
R16: 1M 1%; R0402; DIGIKEY RHM1.00MCDCT-ND
SJ1: JUMPER-PAD-3-NOFULL_BOX_SILK; PAD-JUMPER-3-NO_YES_SILK_FULL_BOX
U1: CC2520; S-PVQFN-N28
U3: CAT24C256WI-GT3
WRT: JUMPER-PTH-2-NO; PTH-JUMPER-2-NO_NO_SILK
X1: NX2520SA

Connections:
5V: P9/P8.P9_7 (SYS_5V0), P9/P8.P9_8 (SYS_5V1)
!RESET0: P9/P8.P9_15 (GPIO1_16), U1.25 (!RESET)
!RESET1: P9/P8.P8_26 (GPIO1_29); also elsewhere on the board
CCA0: P9/P8.P9_12 (GPIO1_28), U1.6 (GPIO3)
CCA1: P9/P8.P8_12 (GPIO1_12); also elsewhere on the board
CC_GPIO0_0: U1.10 (GPIO0)
CC_GPIO5_0: U1.4 (GPIO5)
CS0: P9/P8.P9_17 (I2C1_SCL), U1.3 (!CS)
CS1: P9/P8.P9_16 (EHRPWM1B); also elsewhere on the board
FIFO0: P9/P8.P9_27 (GPIO3_19), U1.9 (GPIO1)
FIFO1: P9/P8.P8_14 (GPIO0_26); also elsewhere on the board
FIFOP0: P9/P8.P9_23 (GPIO1_17), U1.7 (GPIO2)
FIFOP1: P9/P8.P8_11 (GPIO1_13); also elsewhere on the board
GND: B1.2 (GND), B1.5 (GND), B1.6 (GND), C7.2, C8.2, C14.2, C15.2, C16.2, C17.2, C18.2, C23.2, P1.2, P1.3, P1.4, P1.5, P9/P8.P8_1 (GND6), P9/P8.P8_2 (GND7), P9/P8.P9_1 (GND0), P9/P8.P9_2 (GND1), P9/P8.P9_43 (GND2), P9/P8.P9_44 (GND3), P9/P8.P9_45 (GND4), P9/P8.P9_46 (GND5), R13.1, R16.1, SJ1.2, U1.THERMALPAD (GND_EXP), U3.VSS, WRT.2; also elsewhere on the board
LED0: P9/P8.P8_17 (GPIO0_27), R1.1
LED1: P9/P8.P8_18 (GPIO2_1), R2.1
LED2: P9/P8.P8_16 (GPIO1_14), R3.1
MISO: P9/P8.P9_18 (I2C1_SDA), R16.2, U1.1 (MISO); also elsewhere on the board
MOSI: P9/P8.P9_21 (UART2_TXD), U1.2 (MOSI); also elsewhere on the board
unnamed: D1.C, R1.2
unnamed: D2.C, R2.2
unnamed: D3.C, R3.2
unnamed: C14.1, C15.1, C16.1, C23.1, L1.1, U1.8 (DVDD), U1.11 (AVDD5), U1.14 (AVDD3), U1.16 (AVDD2), U1.20 (AVDD1), U1.22 (AVDD4), U1.24 (AVDD0), U1.26 (VREG_EN)
unnamed: B1.1 (ANT), P1.1
unnamed: C8.1, U1.13 (XOSC_Q1), X1.1
unnamed: C17.1, U1.27 (DCOUPL)
unnamed: C7.1, U1.12 (XOSC_Q2), X1.3 (2)
unnamed: R13.2, U1.23 (RBIAS)
unnamed: R7.1, SJ1.1, U3.A0
unnamed: R8.1, SJ1.3, U3.A1
unnamed: R12.2, U3.WP, WRT.1
unnamed: R9.1, U3.A2
RF_N: B1.3 (BAL_N), U1.19 (RF_N)
RF_P: B1.4 (BAL_P), U1.17 (RF_P)
SCL: P9/P8.P9_19 (I2C2_SCL), R10.1, U3.SCL
SCLK: P9/P8.P9_22 (UART2_RXD), U1.28 (SCLK); also elsewhere on the board
SDA: P9/P8.P9_20 (I2C2_SDA), R11.1, U3.SDA
SFD0: P9/P8.P9_14 (EHRPWM1A), U1.5 (GPIO4)
SFD1: P9/P8.P8_15 (GPIO1_15); also elsewhere on the board
VCC: C18.1, D1.A, D2.A, D3.A, L1.2, P9/P8.P9_3 (DC_3.3V0), P9/P8.P9_4 (DC_3.3V1), R7.2, R8.2, R9.2, R10.2, R11.2, R12.1, U3.VCC; also elsewhere on the board
VDD: P9/P8.P9_5 (VDD_5V0), P9/P8.P9_6 (VDD_5V1)

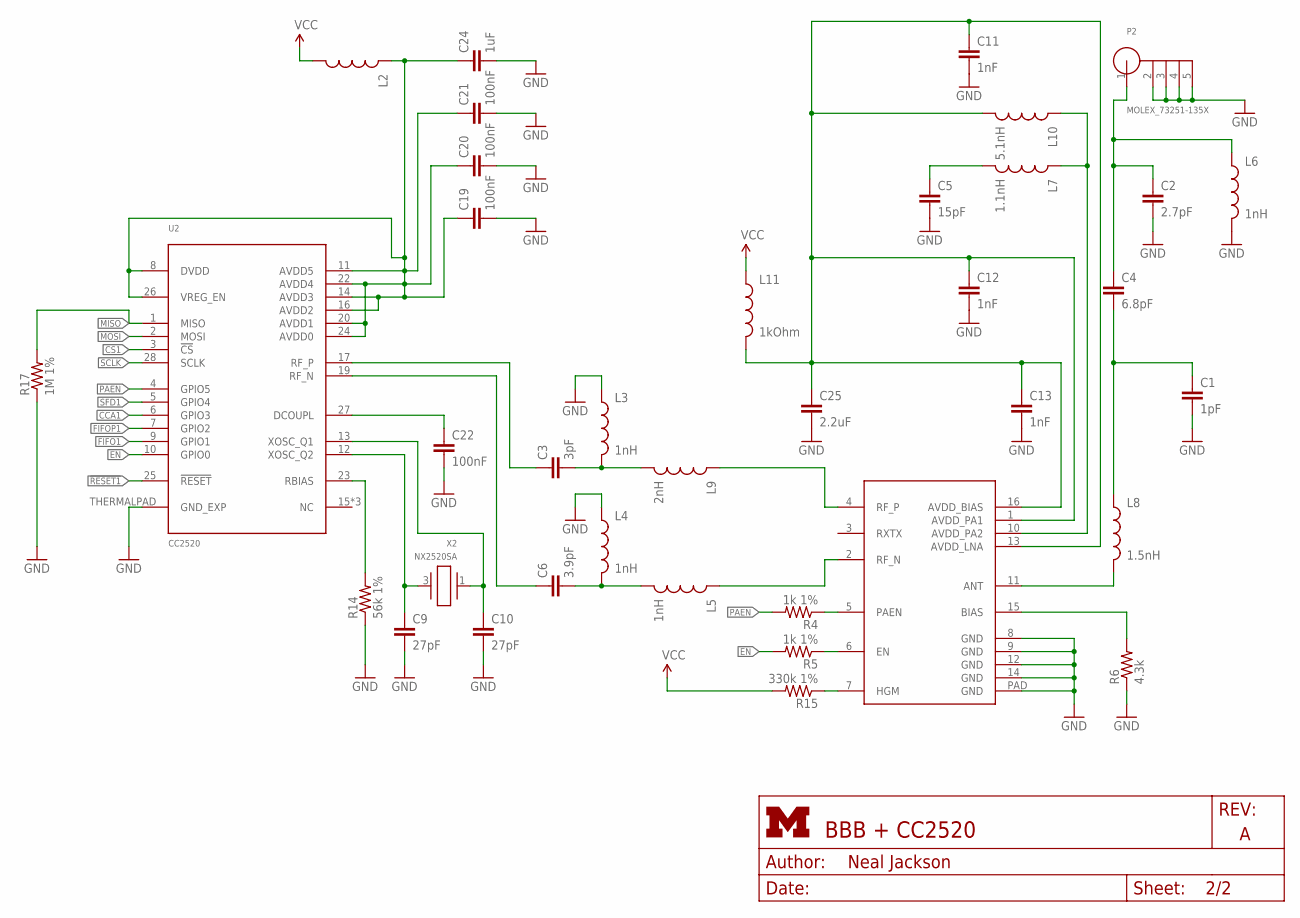
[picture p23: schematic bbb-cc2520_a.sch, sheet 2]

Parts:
C1: 1pF; C0402; DIGIKEY 490-1318-1-ND
C2: 2.7pF; C0402; DIGIKEY 490-1318-1-ND
C3: 3pF; C0402; DIGIKEY 490-1318-1-ND
C4: 6.8pF; C0402; DIGIKEY 490-1318-1-ND
C5: 15pF; C0402; DIGIKEY 490-1318-1-ND
C6: 3.9pF; C0402; DIGIKEY 490-1318-1-ND
C9, C10: 27pF; C0402; DIGIKEY 490-5869-1-ND
C11, C12, C13: 1nF; C0402; DIGIKEY 490-1318-1-ND
C19, C20, C21, C22: 100nF; C0402; DIGIKEY 490-1318-1-ND
C24: 1uF; C0603; DIGIKEY 490-1550-1-ND
C25: 2.2uF; C0402; DIGIKEY 490-1318-1-ND
L2: INDUCTOR0603; 0603; DIGIKEY 490-1015-1-ND
L3, L4, L5, L6: 1nH; C0402
L7: 1.1nH; C0402
L8: 1.5nH; C0402
L9: 2nH; C0402
L10: 5.1nH; C0402
L11: 1kOhm; C0402
P2: MOLEX_73251-135X; SMA-J/PCB
R4, R5: 1k 1%; R0402; DIGIKEY P56.0KLCT-ND
R6: 4.3k; R0402; DIGIKEY P56.0KLCT-ND
R14: 56k 1%; R0402; DIGIKEY P56.0KLCT-ND
R15: 330k 1%; R0402; DIGIKEY P56.0KLCT-ND
R17: 1M 1%; R0402; DIGIKEY RHM1.00MCDCT-ND
U2: CC2520; S-PVQFN-N28
U4: CC2591; PVQFN-16
X2: NX2520SA

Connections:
!RESET1: U2.25 (!RESET); also elsewhere on the board
CCA1: U2.6 (GPIO3); also elsewhere on the board
CS1: U2.3 (!CS); also elsewhere on the board
EN: R5.2, U2.10 (GPIO0)
FIFO1: U2.9 (GPIO1); also elsewhere on the board
FIFOP1: U2.7 (GPIO2); also elsewhere on the board
GND: C1.2, C2.2, C5.2, C9.2, C10.2, C11.2, C12.2, C13.2, C19.2, C20.2, C21.2, C22.2, C24.2, C25.2, L3.1, L4.1, L6.2, P2.2, P2.3, P2.4, P2.5, R6.1, R14.1, R17.1, U2.THERMALPAD (GND_EXP), U4.8 (GND), U4.9 (GND), U4.12 (GND), U4.14 (GND), U4.PAD (GND); also elsewhere on the board
MISO: R17.2, U2.1 (MISO); also elsewhere on the board
MOSI: U2.2 (MOSI); also elsewhere on the board
unnamed: L9.1, U4.4 (RF_P)
unnamed: L5.1, U4.2 (RF_N)
unnamed: C6.2, L4.2, L5.2
unnamed: C3.2, L3.2, L9.2
unnamed: L7.1, L10.1, U4.10 (AVDD_PA2)
unnamed: C11.1, C12.1, C13.1, C25.1, L10.2, L11.2, U4.1 (AVDD_PA1), U4.13 (AVDD_LNA), U4.16 (AVDD_BIAS)
unnamed: C5.1, L7.2
unnamed: L8.2, U4.11 (ANT)
unnamed: C2.1, C4.1, L6.1, P2.1
unnamed: C1.1, C4.2, L8.1
unnamed: R6.2, U4.15 (BIAS)
unnamed: R4.1, U4.5 (PAEN)
unnamed: R5.1, U4.6 (EN)
unnamed: C19.1, C20.1, C21.1, C24.1, L2.1, U2.8 (DVDD), U2.11 (AVDD5), U2.14 (AVDD3), U2.16 (AVDD2), U2.20 (AVDD1), U2.22 (AVDD4), U2.24 (AVDD0), U2.26 (VREG_EN)
unnamed: C22.1, U2.27 (DCOUPL)
unnamed: C10.1, U2.13 (XOSC_Q1), X2.1
unnamed: C9.1, U2.12 (XOSC_Q2), X2.3 (2)
unnamed: R14.2, U2.23 (RBIAS)
unnamed: R15.1, U4.7 (HGM)
PAEN: R4.2, U2.4 (GPIO5)
RF_N2: C6.1, U2.19 (RF_N)
RF_P2: C3.1, U2.17 (RF_P)
SCLK: U2.28 (SCLK); also elsewhere on the board
SFD1: U2.5 (GPIO4); also elsewhere on the board
VCC: L2.2, L11.1, R15.2; also elsewhere on the board

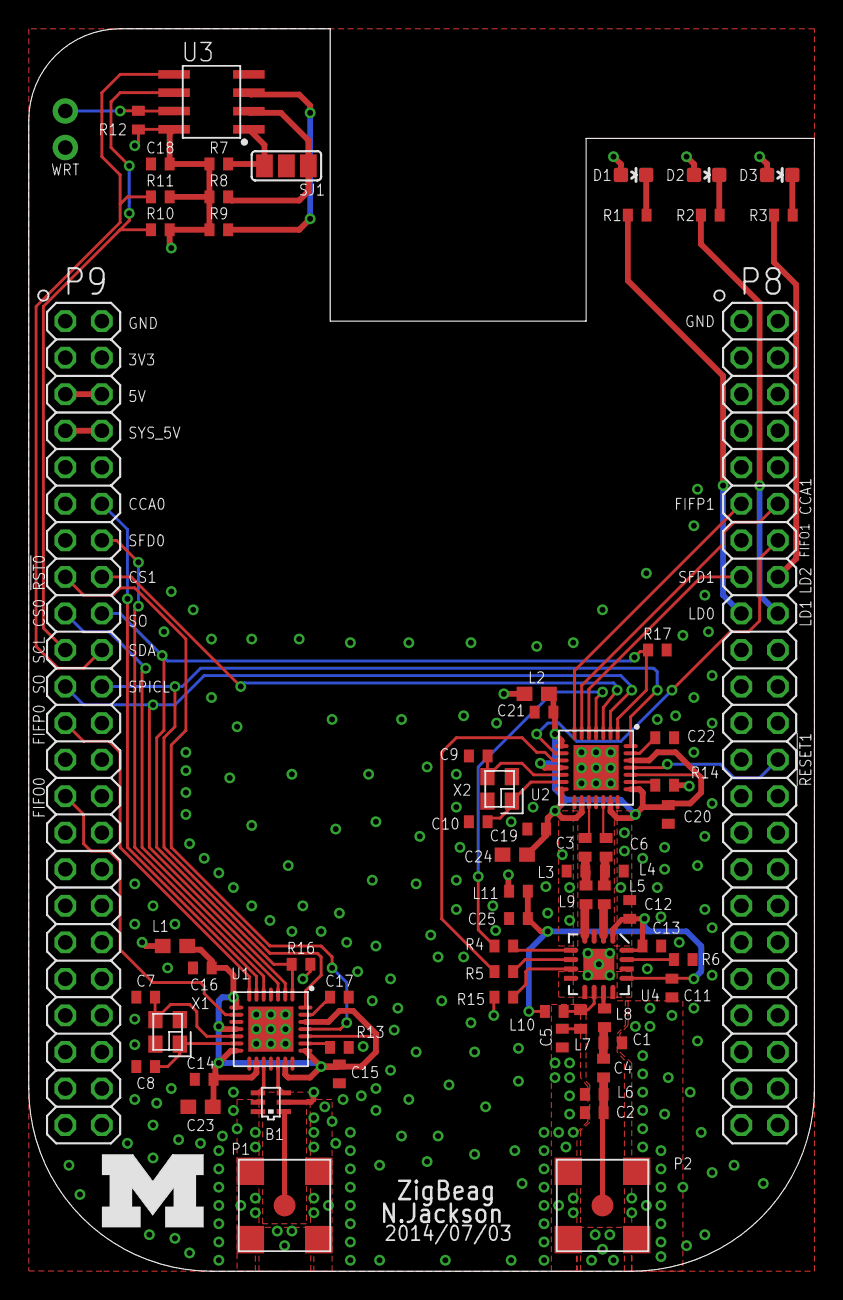
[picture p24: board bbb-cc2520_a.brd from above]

Board: 4 copper layers, 54.6 x 86.4 mm, 69 parts (0 on the bottom side), 62 nets.

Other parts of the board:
U$2: UMICH_SOLID_200MIL

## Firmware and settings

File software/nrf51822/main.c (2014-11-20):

/*

Bluetooth low energy Co-Processor

This app makes the nRF51822 into a BLE SPI slave peripheral.

See bcp.h for the list of valid commands the SPI master can issue.

*/

#include <stdint.h>
#include <stdio.h>
#include <string.h>
#include "nordic_common.h"
#include "nrf_sdm.h"
#include "ble.h"
#include "ble_db_discovery.h"
#include "softdevice_handler.h"
#include "app_util.h"
#include "app_error.h"
#include "ble_advdata_parser.h"
#include "boards.h"
#include "nrf_gpio.h"
#include "pstorage.h"
#include "device_manager.h"
#include "app_trace.h"
#include "ble_hrs_c.h"
#include "ble_bas_c.h"
#include "app_util.h"

#include "led.h"

#include "bcp.h"
#include "interrupt_event_queue.h"
#include "bcp_spi_slave.h"


#define LED_GOT_ADV_PACKET               LED_0                                          /**< Is on when application has asserted. */

#define INTERRUPT_PIN                    7
#define ADV_PIN                    4

#define APPL_LOG                         app_trace_log                                  /**< Debug logger macro that will be used in this file to do logging of debug information over UART. */

#define SEC_PARAM_BOND             1                                  /**< Perform bonding. */
#define SEC_PARAM_MITM             1                                  /**< Man In The Middle protection not required. */
#define SEC_PARAM_IO_CAPABILITIES  BLE_GAP_IO_CAPS_NONE               /**< No I/O capabilities. */
#define SEC_PARAM_OOB              0                                  /**< Out Of Band data not available. */
#define SEC_PARAM_MIN_KEY_SIZE     7                                  /**< Minimum encryption key size. */
#define SEC_PARAM_MAX_KEY_SIZE     16                                 /**< Maximum encryption key size. */

#define SCAN_INTERVAL              0x00A0                             /**< Determines scan interval in units of 0.625 millisecond. */
#define SCAN_WINDOW                0x0050                             /**< Determines scan window in units of 0.625 millisecond. */

#define MIN_CONNECTION_INTERVAL    MSEC_TO_UNITS(7.5, UNIT_1_25_MS)   /**< Determines maximum connection interval in millisecond. */
#define MAX_CONNECTION_INTERVAL    MSEC_TO_UNITS(30, UNIT_1_25_MS)    /**< Determines maximum connection interval in millisecond. */
#define SLAVE_LATENCY              0                                  /**< Determines slave latency in counts of connection events. */
#define SUPERVISION_TIMEOUT        MSEC_TO_UNITS(4000, UNIT_10_MS)    /**< Determines supervision time-out in units of 10 millisecond. */

#define TARGET_UUID                0x180D                             /**< Target device name that application is looking for. */
#define MAX_PEER_COUNT             DEVICE_MANAGER_MAX_CONNECTIONS     /**< Maximum number of peer's application intends to manage. */
#define UUID16_SIZE                2                                  /**< Size of 16 bit UUID */

/**@breif Macro to unpack 16bit unsigned UUID from octet stream. */
#define UUID16_EXTRACT(DST,SRC)                                                                  \
        do                                                                                       \
        {                                                                                        \
            (*(DST)) = (SRC)[1];                                                                 \
            (*(DST)) <<= 8;                                                                      \
            (*(DST)) |= (SRC)[0];                                                                \
        } while(0)

/**@brief Variable length data encapsulation in terms of length and pointer to data */
typedef struct
{
    uint8_t     * p_data;                                         /**< Pointer to data. */
    uint16_t      data_len;                                       /**< Length of data. */
}data_t;

typedef enum
{
    BLE_NO_SCAN,                                                  /**< No advertising running. */
    BLE_WHITELIST_SCAN,                                           /**< Advertising with whitelist. */
    BLE_FAST_SCAN,                                                /**< Fast advertising running. */
} ble_advertising_mode_t;

static ble_db_discovery_t           m_ble_db_discovery;                  /**< Structure used to identify the DB Discovery module. */
static ble_hrs_c_t                  m_ble_hrs_c;                         /**< Structure used to identify the heart rate client module. */
static ble_bas_c_t                  m_ble_bas_c;                         /**< Structure used to identify the Battery Service client module. */
static ble_gap_scan_params_t        m_scan_param;                        /**< Scan parameters requested for scanning and connection. */
static dm_application_instance_t    m_dm_app_id;                         /**< Application identifier. */
static dm_handle_t                  m_dm_device_handle;                  /**< Device Identifier identifier. */
static uint8_t                      m_peer_count = 0;                    /**< Number of peer's connected. */
static uint8_t                      m_scan_mode;                         /**< Scan mode used by application. */

static bool                         m_memory_access_in_progress = false; /**< Flag to keep track of ongoing operations on persistent memory. */

/**
 * @brief Connection parameters requested for connection.
 */
static const ble_gap_conn_params_t m_connection_param =
{
    (uint16_t)MIN_CONNECTION_INTERVAL,   // Minimum connection
    (uint16_t)MAX_CONNECTION_INTERVAL,   // Maximum connection
    0,                                   // Slave latency
    (uint16_t)SUPERVISION_TIMEOUT        // Supervision time-out
};

static void scan_start(void);

#define APPL_LOG                        app_trace_log             /**< Debug logger macro that will be used in this file to do logging of debug information over UART. */

// WARNING: The following macro MUST be un-defined (by commenting out the definition) if the user
// does not have a nRF6350 Display unit. If this is not done, the application will not work.
//#define APPL_LCD_PRINT_ENABLE                                     /**< In case you do not have a functional display unit, disable this flag and observe trace on UART. */

#ifdef APPL_LCD_PRINT_ENABLE

#define APPL_LCD_CLEAR                  nrf6350_lcd_clear         /**< Macro to clear the LCD display.*/
#define APPL_LCD_WRITE                  nrf6350_lcd_write_string  /**< Macro to write a string to the LCD display.*/

#else // APPL_LCD_PRINT_ENABLE

#define APPL_LCD_WRITE(...)             true                      /**< Macro to clear the LCD display defined to do nothing when @ref APPL_LCD_PRINT_ENABLE is not defined.*/
#define APPL_LCD_CLEAR(...)             true                      /**< Macro to write a string to the LCD display defined to do nothing when @ref APPL_LCD_PRINT_ENABLE is not defined.*/

#endif // APPL_LCD_PRINT_ENABLE




bool bcp_irq_advertisements = false;
//bool bcp_irq_advertisements = true;






/**@brief Function for error handling, which is called when an error has occurred.
 *
 * @warning This handler is an example only and does not fit a final product. You need to analyze
 *          how your product is supposed to react in case of error.
 *
 * @param[in] error_code  Error code supplied to the handler.
 * @param[in] line_num    Line number where the handler is called.
 * @param[in] p_file_name Pointer to the file name.
 */
void app_error_handler(uint32_t error_code, uint32_t line_num, const uint8_t * p_file_name)
{
    // APPL_LOG("[APPL]: ASSERT: %s, %d, error 0x%08x\r\n", p_file_name, line_num, error_code);
    // nrf_gpio_pin_set(ASSERT_LED_PIN_NO);

    // This call can be used for debug purposes during development of an application.
    // @note CAUTION: Activating this code will write the stack to flash on an error.
    //                This function should NOT be used in a final product.
    //                It is intended STRICTLY for development/debugging purposes.
    //                The flash write will happen EVEN if the radio is active, thus interrupting
    //                any communication.
    //                Use with care. Un-comment the line below to use.
    // ble_debug_assert_handler(error_code, line_num, p_file_name);

    // On assert, the system can only recover with a reset.
    NVIC_SystemReset();
}


/**@brief Function for asserts in the SoftDevice.
 *
 * @details This function will be called in case of an assert in the SoftDevice.
 *
 * @warning This handler is an example only and does not fit a final product. You need to analyze
 *          how your product is supposed to react in case of Assert.
 * @warning On assert from the SoftDevice, the system can only recover on reset.
 *
 * @param[in] line_num     Line number of the failing ASSERT call.
 * @param[in] p_file_name  File name of the failing ASSERT call.
 */
void assert_nrf_callback(uint16_t line_num, const uint8_t * p_file_name)
{
    app_error_handler(0xDEADBEEF, line_num, p_file_name);
}



// Send all received advertisements to the host
void bcp_sniff_advertisements () {
    led_on(LED_0);
    bcp_irq_advertisements = true;
}



void bcp_interrupt_host () {
    nrf_gpio_pin_set(INTERRUPT_PIN);
}

void bcp_interupt_host_clear () {
    nrf_gpio_pin_clear(INTERRUPT_PIN);
}




/**@brief Callback handling device manager events.
 *
 * @details This function is called to notify the application of device manager events.
 *
 * @param[in]   p_handle      Device Manager Handle. For link related events, this parameter
 *                            identifies the peer.
 * @param[in]   p_event       Pointer to the device manager event.
 * @param[in]   event_status  Status of the event.
 */
static api_result_t device_manager_event_handler(const dm_handle_t    * p_handle,
                                                 const dm_event_t     * p_event,
                                                 const api_result_t     event_result)
{
//     bool     lcd_write_status;
//     uint32_t err_code;

//     switch(p_event->event_id)
//     {
//         case DM_EVT_CONNECTION:
//         {
//             APPL_LOG("[APPL]: >> DM_EVT_CONNECTION\r\n");
// #ifdef ENABLE_DEBUG_LOG_SUPPORT
//             ble_gap_addr_t * peer_addr;
//             peer_addr = &p_event->event_param.p_gap_param->params.connected.peer_addr;
// #endif // ENABLE_DEBUG_LOG_SUPPORT
//             APPL_LOG("[APPL]:[%02X %02X %02X %02X %02X %02X]: Connection Established\r\n",
//                                 peer_addr->addr[0], peer_addr->addr[1], peer_addr->addr[2],
//                                 peer_addr->addr[3], peer_addr->addr[4], peer_addr->addr[5]);

//             nrf_gpio_pin_set(CONNECTED_LED_PIN_NO);
//             lcd_write_status = APPL_LCD_WRITE("Connected", 9, LCD_UPPER_LINE, 0);
//             if (!lcd_write_status)
//             {
//                 APPL_LOG("[APPL]: LCD Write failed!\r\n");
//             }
//             m_dm_device_handle = (*p_handle);

//             // Discover peer's services.
//              err_code = ble_db_discovery_start(&m_ble_db_discovery,
//                                                p_event->event_param.p_gap_param->conn_handle);
//             APP_ERROR_CHECK(err_code);

//             m_peer_count++;
//             if (m_peer_count < MAX_PEER_COUNT)
//             {
//                 scan_start();
//             }
//             APPL_LOG("[APPL]: << DM_EVT_CONNECTION\r\n");
//             break;
//         }

//         case DM_EVT_DISCONNECTION:
//         {
//             APPL_LOG("[APPL]: >> DM_EVT_DISCONNECTION\r\n");
//             memset(&m_ble_db_discovery, 0 , sizeof (m_ble_db_discovery));
//             lcd_write_status = APPL_LCD_CLEAR();
//             if (!lcd_write_status)
//             {
//                 APPL_LOG("[APPL]: LCD Clear failed!\r\n");
//             }

//             lcd_write_status = APPL_LCD_WRITE("Disconnected", 12, LCD_UPPER_LINE, 0);
//             if (!lcd_write_status)
//             {
//                 APPL_LOG("[APPL]:[4]: LCD Write failed!\r\n");
//             }

//             nrf_gpio_pin_clear(CONNECTED_LED_PIN_NO);
//             if (m_peer_count == MAX_PEER_COUNT)
//             {
//                 scan_start();
//             }
//             m_peer_count--;
//             APPL_LOG("[APPL]: << DM_EVT_DISCONNECTION\r\n");
//             break;
//         }

//         case DM_EVT_SECURITY_SETUP:
//         {
//             APPL_LOG("[APPL]:[0x%02X] >> DM_EVT_SECURITY_SETUP\r\n", p_handle->connection_id);
//             // Slave securtiy request received from peer, if from a non bonded device,
//             // initiate security setup, else, wait for encryption to complete.
//             err_code = dm_security_setup_req(&m_dm_device_handle);
//             APP_ERROR_CHECK(err_code);
//             APPL_LOG("[APPL]:[0x%02X] << DM_EVT_SECURITY_SETUP\r\n", p_handle->connection_id);
//             break;
//         }
//         case DM_EVT_SECURITY_SETUP_COMPLETE:
//         {
//             APPL_LOG("[APPL]: >> DM_EVT_SECURITY_SETUP_COMPLETE\r\n");
//              // Heart rate service discovered. Enable notification of Heart Rate Measurement.
//             err_code = ble_hrs_c_hrm_notif_enable(&m_ble_hrs_c);
//             APP_ERROR_CHECK(err_code);
//             APPL_LOG("[APPL]: << DM_EVT_SECURITY_SETUP_COMPLETE\r\n");
//             break;
//         }

//         case DM_EVT_LINK_SECURED:
//             APPL_LOG("[APPL]: >> DM_LINK_SECURED_IND\r\n");
//             APPL_LOG("[APPL]: << DM_LINK_SECURED_IND\r\n");
//             break;

//         case DM_EVT_DEVICE_CONTEXT_LOADED:
//             APPL_LOG("[APPL]: >> DM_EVT_LINK_SECURED\r\n");
//             APP_ERROR_CHECK(event_result);
//             APPL_LOG("[APPL]: << DM_EVT_DEVICE_CONTEXT_LOADED\r\n");
//             break;

//         case DM_EVT_DEVICE_CONTEXT_STORED:
//             APPL_LOG("[APPL]: >> DM_EVT_DEVICE_CONTEXT_STORED\r\n");
//             APP_ERROR_CHECK(event_result);
//             APPL_LOG("[APPL]: << DM_EVT_DEVICE_CONTEXT_STORED\r\n");
//             break;

//         case DM_EVT_DEVICE_CONTEXT_DELETED:
//             APPL_LOG("[APPL]: >> DM_EVT_DEVICE_CONTEXT_DELETED\r\n");
//             APP_ERROR_CHECK(event_result);
//             APPL_LOG("[APPL]: << DM_EVT_DEVICE_CONTEXT_DELETED\r\n");
//             break;

//         default:
//             break;
//     }

    return NRF_SUCCESS;
}


/**
 * @brief Parses advertisement data, providing length and location of the field in case
 *        matching data is found.
 *
 * @param[in]  Type of data to be looked for in advertisement data.
 * @param[in]  Advertisement report length and pointer to report.
 * @param[out] If data type requested is found in the data report, type data length and
 *             pointer to data will be populated here.
 *
 * @retval NRF_SUCCESS if the data type is found in the report.
 * @retval NRF_ERROR_NOT_FOUND if the data type could not be found.
 */
static uint32_t adv_report_parse(uint8_t type, data_t * p_advdata, data_t * p_typedata)
{
    uint32_t index = 0;
    uint8_t * p_data;

    p_data = p_advdata->p_data;

    while (index < p_advdata->data_len)
    {
        uint8_t field_length = p_data[index];
        uint8_t field_type = p_data[index+1];

        if (field_type == type)
        {
            p_typedata->p_data = &p_data[index+2];
            p_typedata->data_len = field_length-1;
            return NRF_SUCCESS;
        }
        index += field_length+1;
    }
    return NRF_ERROR_NOT_FOUND;
}


/**@brief Function for handling the Application's BLE Stack events.
 *
 * @param[in]   p_ble_evt   Bluetooth stack event.
 */
static void on_ble_evt(ble_evt_t * p_ble_evt)
{
    uint32_t                err_code;
    const ble_gap_evt_t   * p_gap_evt = &p_ble_evt->evt.gap_evt;

    switch (p_ble_evt->header.evt_id)
    {
        case BLE_GAP_EVT_ADV_REPORT:
        {

            //led_off(LED_GOT_ADV_PACKET);


    nrf_gpio_pin_toggle(ADV_PIN);


            if (bcp_irq_advertisements) {
                interrupt_event_queue_add(BCP_RSP_ADVERTISEMENT,
                                          p_gap_evt->params.adv_report.dlen+8,
                                          (uint8_t*)&p_gap_evt->params.adv_report);

                   //nrf_gpio_pin_toggle(INTERRUPT_PIN);
            }


            // data_t adv_data;
            // data_t type_data;

            // // Initialize advertisement report for parsing.
            // adv_data.p_data = (uint8_t *)p_gap_evt->params.adv_report.data;
            // adv_data.data_len = p_gap_evt->params.adv_report.dlen;

            // err_code = adv_report_parse(BLE_GAP_AD_TYPE_16BIT_SERVICE_UUID_MORE_AVAILABLE,
            //                             &adv_data,
            //                             &type_data);
            // if (err_code != NRF_SUCCESS)
            // {
            //     // Compare short local name in case complete name does not match.
            //     err_code = adv_report_parse(BLE_GAP_AD_TYPE_16BIT_SERVICE_UUID_COMPLETE,
            //                                 &adv_data,
            //                                 &type_data);
            // }

            // // Verify if short or complete name matches target.
            // if (err_code == NRF_SUCCESS)
            // {
            //     uint16_t extracted_uuid;

            //     // UUIDs found, look for matching UUID
            //     for (uint32_t u_index = 0; u_index < (type_data.data_len/UUID16_SIZE); u_index++)
            //     {
            //         UUID16_EXTRACT(&extracted_uuid,&type_data.p_data[u_index * UUID16_SIZE]);

            //         APPL_LOG("\t[APPL]: %x\r\n",extracted_uuid);

            //         if(extracted_uuid == TARGET_UUID)
            //         {
            //             // Stop scanning.
            //             err_code = sd_ble_gap_scan_stop();
            //             if (err_code != NRF_SUCCESS)
            //             {
            //                 APPL_LOG("[APPL]: Scan stop failed, reason %d\r\n", err_code);
            //             }
            //             nrf_gpio_pin_clear(SCAN_LED_PIN_NO);

            //             m_scan_param.selective = 0;

            //             // Initiate connection.
            //             err_code = sd_ble_gap_connect(&p_gap_evt->params.adv_report.\
            //                                            peer_addr,
            //                                            &m_scan_param,
            //                                            &m_connection_param);

            //             if (err_code != NRF_SUCCESS)
            //             {
            //                 APPL_LOG("[APPL]: Connection Request Failed, reason %d\r\n", err_code);
            //             }
            //             break;
            //         }
            //     }
            // }
            break;
        }
        case BLE_GAP_EVT_TIMEOUT:
            // if(p_gap_evt->params.timeout.src == BLE_GAP_TIMEOUT_SRC_SCAN)
            // {
            //     APPL_LOG("[APPL]: Scan timed out.\r\n");
            //     if (m_scan_mode ==  BLE_WHITELIST_SCAN)
            //     {
            //         m_scan_mode = BLE_FAST_SCAN;

            //         // Start non selective scanning.
            //         scan_start();
            //     }
            // }
            // else if (p_gap_evt->params.timeout.src == BLE_GAP_TIMEOUT_SRC_CONN)
            // {
            //     APPL_LOG("[APPL]: Connection Request timed out.\r\n");
            // }
            break;
        case BLE_GAP_EVT_CONN_PARAM_UPDATE_REQUEST:
            // // Accepting parameters requested by peer.
            // err_code = sd_ble_gap_conn_param_update(p_gap_evt->conn_handle,
            //                                         &p_gap_evt->params.conn_param_update_request.conn_params);
            // APP_ERROR_CHECK(err_code);
            break;
        default:
            break;
    }
}

/**@brief Function for handling the Application's system events.
 *
 * @param[in]   sys_evt   system event.
 */
static void on_sys_evt(uint32_t sys_evt)
{
    switch(sys_evt)
    {
        case NRF_EVT_FLASH_OPERATION_SUCCESS:
        case NRF_EVT_FLASH_OPERATION_ERROR:
            if (m_memory_access_in_progress)
            {
                m_memory_access_in_progress = false;
                scan_start();
            }
            break;
        default:
            // No implementation needed.
            break;
    }
}


/**@brief Function for dispatching a BLE stack event to all modules with a BLE stack event handler.
 *
 * @details This function is called from the scheduler in the main loop after a BLE stack event has
 *  been received.
 *
 * @param[in]   p_ble_evt   Bluetooth stack event.
 */
static void ble_evt_dispatch(ble_evt_t * p_ble_evt)
{
   // dm_ble_evt_handler(p_ble_evt);
   // ble_db_discovery_on_ble_evt(&m_ble_db_discovery, p_ble_evt);
   // ble_hrs_c_on_ble_evt(&m_ble_hrs_c, p_ble_evt);
   // ble_bas_c_on_ble_evt(&m_ble_bas_c, p_ble_evt);
    on_ble_evt(p_ble_evt);
}
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
int main(void)
{
    // Initialization of various modules.
 //   app_trace_init();
    led_init(LED_GOT_ADV_PACKET);

    nrf_gpio_cfg_output(INTERRUPT_PIN);
    nrf_gpio_pin_clear(INTERRUPT_PIN);



    nrf_gpio_cfg_output(ADV_PIN);
    nrf_gpio_pin_clear(ADV_PIN);

    nrf_gpio_cfg_output(3);
    nrf_gpio_pin_clear(3);

    led_on(LED_GOT_ADV_PACKET);


    ble_stack_init();

    spi_slave_example_init();


    device_manager_init();
    db_discovery_init();


  //  hrs_c_init();
  //  bas_c_init();

    // Start scanning for peripherals and initiate connection
    // with devices that advertise Heart Rate UUID.
    scan_start();


    led_off(LED_GOT_ADV_PACKET);

    for (;;)
    {
        power_manage();
    }
}

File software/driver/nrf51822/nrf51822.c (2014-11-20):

#include <linux/kernel.h>
#include <linux/module.h>
#include <linux/fs.h>
#include <asm/uaccess.h>
#include <linux/types.h>
#include <linux/semaphore.h>
#include <linux/slab.h>
#include <linux/sched.h>
#include <linux/cdev.h>
#include <linux/device.h>
#include <linux/interrupt.h>
#include <linux/spi/spi.h>
#include <linux/gpio.h>
#include <linux/delay.h>
#include <linux/poll.h>
#include <linux/of_gpio.h>
#include <linux/platform_device.h>

#include "../gapspi/gapspi.h"

#include "nrf51822.h"
#include "bcp.h"
#include "ioctl.h"
#include "debug.h"

#define DRIVER_AUTHOR  "Brad Campbell <bradjc@umich.edu>"
#define DRIVER_DESC    "A driver for the nRF51822 BLE chip over SPI."
#define DRIVER_VERSION "0.2"

const char nrf51822_name[] = "nRF51822";
struct nrf51822_config config;

// Not implemented currently
static ssize_t nrf51822_write(struct file *filp,
                               const char *in_buf,
                               size_t len,
                               loff_t * off)
{
		return -EFAULT;
}

// Called by the read() command from user space
static ssize_t nrf51822_read(struct file *filp,
                              char __user *buf,
                              size_t count,
                              loff_t *offp)
{
	int result;
	int user_len;
	struct nrf51822_dev *dev = filp->private_data;

	// Wait for data to be ready to send to the user.
	wait_event_interruptible(dev->to_user_queue, (dev->buf_to_user_len > 0));

	// Copy the result from the nRF51822 to the user
	result  = copy_to_user(buf, dev->buf_to_user, dev->buf_to_user_len);
	if (result) {
		return -EFAULT;
	}

	user_len = dev->buf_to_user_len;

	// Reset the buffer length so the user_queue wait doesn't trigger
	dev->buf_to_user_len = 0;

	return user_len;
}

static long nrf51822_ioctl(struct file *file,
							unsigned int ioctl_num,
							unsigned long ioctl_param)
{
	int result;
	struct nrf51822_dev *dev = file->private_data;

	switch (ioctl_num) {
		case NRF51822_IOCTL_SET_DEBUG_VERBOSITY:
			result = nrf51822_ioctl_set_debug_verbosity((struct nrf51822_set_debug_verbosity_data*) ioctl_param);
			break;
		case NRF51822_IOCTL_SIMPLE_COMMAND:
			result = nrf51822_ioctl_simple_command((struct nrf51822_simple_command*) ioctl_param, dev);
			break;
		default:
			result = -ENOTTY;
	}

	return result;
}

static unsigned int nrf51822_poll (struct file *file, poll_table *wait)
{
	unsigned int mask = 0;
	struct nrf51822_dev *dev = file->private_data;

	poll_wait(file, &dev->to_user_queue, wait);

	// always writable
	mask |= POLLOUT | POLLWRNORM;

	if (dev->buf_to_user_len > 0) {
		// readable
		mask |= POLLIN | POLLRDNORM;
	}

	return mask;
}

static int nrf51822_open(struct inode *inode, struct file *filp)
{
	struct nrf51822_dev *dev;
	dev = container_of(inode->i_cdev, struct nrf51822_dev, cdev);
	filp->private_data = dev;
	DBG(KERN_INFO, "opening radio%d.\n", dev->id);

	return 0;
}

struct file_operations fops = {
	.read = nrf51822_read,
	.write = nrf51822_write,
	.unlocked_ioctl = nrf51822_ioctl,
	.open = nrf51822_open,
	.release = NULL,
	.poll = nrf51822_poll
};

///////////////////
// IOCTL Handlers
///////////////////

// Change the print verbosity
static int nrf51822_ioctl_set_debug_verbosity(struct nrf51822_set_debug_verbosity_data *data)
{
	int result;
	struct nrf51822_set_debug_verbosity_data ldata;

	result = copy_from_user(&ldata, data, sizeof(struct nrf51822_set_debug_verbosity_data));

	if (result) {
		ERR(KERN_ALERT, "an error occurred setting print messages\n");
		return 0;
	}

	INFO(KERN_INFO, "setting debug message print: %i", ldata.debug_level);

	config.debug_print = ldata.debug_level;

	return 0;
}

// Issue a command to the nRF51822. These are 1 byte commands.
static int nrf51822_ioctl_simple_command(struct nrf51822_simple_command *data, struct nrf51822_dev *dev)
{
	int result;
	struct nrf51822_simple_command ldata;

	result = copy_from_user(&ldata, data, sizeof(struct nrf51822_simple_command));

	if (result) {
		ERR(KERN_ALERT, "an error occurred a command\n");
		return 0;
	}

	INFO(KERN_INFO, "issuing command: %i", ldata.command);

	return nrf51822_issue_simple_command(ldata.command, dev);
}


/////////////////////
// Application logic
/////////////////////

// Manually check if the interrupt line is high.
static void nrf51822_check_irq (struct nrf51822_dev *dev) {
	// Check if we need to read the IRQ again
	if (gpio_get_value(dev->pin_interrupt) == 1) {
		// Interrupt is still high.
		// Read again.

		// Put this delay here so the nRF51822 has time to set the SPI buffer
		// again.
		usleep_range(25, 50);

		nrf51822_read_irq(dev);
	}
}


// The result of the interrupt is in spi_buffer
static void nrf51822_read_irq_done (void *arg) {
	struct nrf51822_dev *dev = arg;
	int len;

	DBG(KERN_INFO, "Got IRQ data from nrf51822\n");

	// There is an issue where the nRF51822 needs 7.1us between CS and CLK.
	// We violate that currently, so the first byte may be invalid (0x00).
	// If the second byte was zero as well, that denotes an error.
	if (dev->spi_data_buffer[0] == 0 && dev->spi_data_buffer[1] == 0) {
		// This was an invalid transfer. Some error occurred.

		ERR(KERN_INFO, "First two bytes zero. Ignoring response from nRF51822:%i\n", dev->id);

		spin_lock_irqsave(&dev->spi_spin_lock, dev->spi_spin_lock_flags);
		dev->spi_pending = false;
		spin_unlock_irqrestore(&dev->spi_spin_lock, dev->spi_spin_lock_flags);

		nrf51822_check_irq(dev);

		return;

	} else if (dev->spi_data_buffer[0] == 0) {
		// The first byte was an error. Skip it and use the second byte
		// as the length.
		len = dev->spi_data_buffer[1]+1;

		// Move the packet from the SPI buffer to the thing that can be read()
		memcpy(dev->buf_to_user, dev->spi_data_buffer, len);
		dev->buf_to_user_len = len;

	} else {
		// The first byte was the length
		len = dev->spi_data_buffer[0]+1;

		// Move the packet from the SPI buffer to the thing that can be read()
		memcpy(dev->buf_to_user, dev->spi_data_buffer, len);
		dev->buf_to_user_len = len;
	}

	// Release the lock on the SPI buffer
	spin_lock_irqsave(&dev->spi_spin_lock, dev->spi_spin_lock_flags);
	dev->spi_pending = false;
	spin_unlock_irqrestore(&dev->spi_spin_lock, dev->spi_spin_lock_flags);

	// Notify the read() call that there is data for it.
	wake_up(&dev->to_user_queue);

	nrf51822_check_irq(dev);
}
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

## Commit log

2014-06-30 Update README.md
    Added link to original raspi board
2014-06-30 Added beaglebone black cc2520 driver and DTO source
2014-06-30 added initial information on driver, board and tinyOS
2014-07-10 updated pin layout to better utilize primary GPIOs
2014-07-10 added compiled device tree overlay (.dtbo)
2014-07-11 fixed board naming in eepromflasher
2014-07-15 changed pin assignments in driver to match new board
2014-07-15 compiled new driver with new pin config
2014-07-16 got device tree overlay to load cc2520 driver instead of spidev on load
2014-07-16 added install script for DTO and driver
2014-07-16 One radio down, one to go
    [bbb-cc2520_a.brd]
2014-07-16 forgot to add schematic
    [bbb-cc2520_a.sch]
2014-07-21 depmod only updates cc2520 driver, rather than all of them. Made copy calls verbose to make it clearer what the script is doing
2014-07-21 Changed pinout again. Now using a GPIO as chip select instead of the SPI one. This will allow more radios to interface to the SPI0.
2014-07-22 compiled most recent driver to reflect gpio and spi changes
2014-07-22 finished routing both radios, rf traces
    [bbb-cc2520_a.brd, bbb-cc2520_a.sch]
2014-07-24 finished initial rev a board layout, changes may come soon
    [bbb-cc2520_a.brd, bbb-cc2520_a.sch]
2014-07-25 fixed labeling and vias
    [bbb-cc2520_a.brd, bbb-cc2520_a.sch]
2014-07-29 rev a finished, gerbers generated, bom done
    [bbb-cc2520_a.brd, bbb-cc2520_a.sch, bbb-cc2520_a_bom.xlsx]
2014-07-29 compiled kernel driver
2014-07-29 restructured char device setup errors, began working on device specific semaphores
2014-07-31 interrupts now tied to device, still need to change other code over
2014-08-04 changed .dts to reflect pins for second radio. changed driver read spi to dynamically operate chip select, removed unnecessary gpio calls to cs
2014-08-04 irq now initialized on device open
2014-08-05 migrating rx over to using multiple devices
2014-08-05 migrate read to use multiple devices
    [bbb-cc2520_a_bom.xlsx]
2014-08-19 swapped spi d0 d1 to match board
2014-08-20 changed device tree overlay to swap SPI d0, d1. Added compiled read/write tests for radio0 and radio1
2014-08-26 began hardware rev b
    [bbb-cc2520_b.brd, bbb-cc2520_b.csv, bbb-cc2520_b.sch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]
2014-09-18 revb mostly finished, need to add BLE chip
    [bbb-cc2520_b.brd, bbb-cc2520_b.sch, bbb-cc2520_b_bom.xlsx]
2014-09-19 compiled driver
2014-10-19 RevB finished
    [bbb-cc2520_b.brd, bbb-cc2520_b.csv, bbb-cc2520_b.sch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]
2014-10-20 updated nrf51822 kernel driver
    can issue commands!
    [nrf51822.c]
2014-10-21 driver seems to work
2014-10-21 cleaned up driver
2014-10-21 driver now working with revb hardware, radio0
2014-11-14 began work on gapspi driver
2014-11-14 added export_symbol statements for spi calls
2014-11-16 nrf and gap drivers seem to work!
2014-11-16 better printout in nrf test
2014-11-17 request gapspi from nrf driver
2014-11-17 added label for bluetooth irq
    [bbb-cc2520_b.brd, bbb-cc2520_b.sch]
2014-11-18 copy spi message buffers
    two radios don't conflict now
2014-11-18 updated symbol for demux, added test points
    [bbb-cc2520_b.brd, bbb-cc2520_b.sch]
2014-11-18 updated device tree overlay to include new drivers
2014-11-18 update overlay
    - rename things
    - move gpios to correct blocks
    - setup leds
2014-11-18 working on autoload drivers
    making drivers better
2014-11-18 update printf in cc2520
    better macro
2014-11-19 refactor
    get rid of all arrays. make device struct per radio
2014-11-19 made changes to board in regards to issue 3
    [bbb-cc2520_b.brd, bbb-cc2520_b.sch]
2014-11-19 cleaned up pcb
    [bbb-cc2520_b.brd, bbb-cc2520_b.sch]
2014-11-19 updated schematic
    [bbb-cc2520_b.brd, bbb-cc2520_b.sch]
2014-11-19 create rev c
    [bbb-cc2520.brd, bbb-cc2520.sch, bbb-cc2520_bom.xlsx]
2014-11-19 restore rev b
    [bbb-cc2520_b.brd, bbb-cc2520_b.sch]
2014-11-20 remove led
2014-11-20 cleaned up SDA trace on eeprom
    [bbb-cc2520.brd]
2014-11-20 board cleaned up
    [bbb-cc2520.brd, bbb-cc2520.sch, bbb-cc2520_bom.xlsx]
2014-11-20 slight change to schematic
    [bbb-cc2520.sch]
2014-11-20 update readme with all of the driver changes
2014-11-20 added board stackup information
2014-11-20 ship rev c
    [bbb-cc2520_bom.csv]
2015-01-08 added uart1 pins to dts
2015-01-09 added pin number comments, reset and uart reservations
2015-01-09 updated eeprom pin config
2015-01-13 changed default channel to 19, updated device file name removed outdated reload.sh from cc2520
2015-01-13 updated write.c, channel 19, device file name
2015-01-22 added ioctl to toggle address filtering
2015-02-27 device tree for using gap with linux drivers
    - need to change hw to use spi1 for cc2520s and spi0 for mux
2015-04-04 rev d
    [bbb-cc2520.brd, bbb-cc2520.sch, bbb-cc2520_bom.csv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]
2015-04-14 moved cs0 pin
    [bbb-cc2520.brd]
2015-04-14 committing changes to gap
    [bbb-cc2520.brd, bbb-cc2520.sch]
2015-06-12 mouse bites
    [bbb-cc2520.brd]
2015-10-22 created overlay for rev d board
    wow. that was hard.
2015-10-23 cleaning up kernel drivers folder
2015-10-23 remove old device tree stuff and guides
2016-06-17 add mounting plate for making BBB magnetic
    [beagle_bone_gateway_magnet_plate.SLDPRT, beagle_bone_gateway_magnet_plate.STL, beagle_bone_gateway_magnet_plate_v2.STL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]

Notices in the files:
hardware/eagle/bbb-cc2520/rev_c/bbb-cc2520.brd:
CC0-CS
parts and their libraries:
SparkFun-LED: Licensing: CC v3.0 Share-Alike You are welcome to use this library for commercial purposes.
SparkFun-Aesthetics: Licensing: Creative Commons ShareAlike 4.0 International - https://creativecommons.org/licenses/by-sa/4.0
